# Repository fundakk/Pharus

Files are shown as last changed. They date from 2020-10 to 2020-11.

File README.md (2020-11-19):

# Pharus

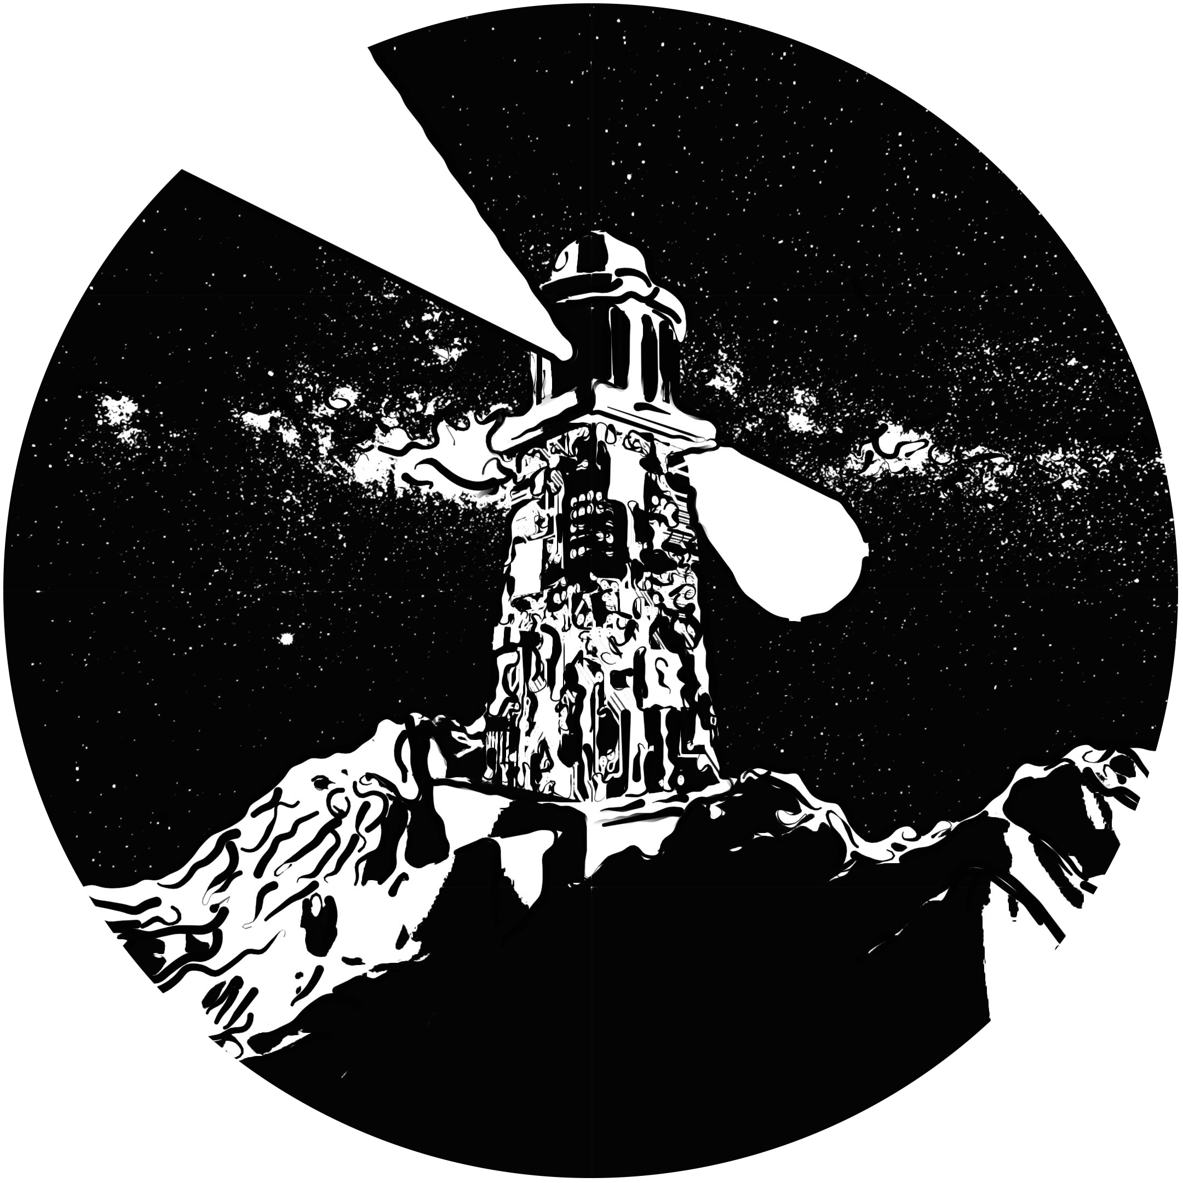
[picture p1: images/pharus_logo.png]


## Table of Content

- [1. Idea](#1-idea)
- [2. Hardware](#2-hardware)
  - [2.1 Basic assumptions](#21-basic-assumptions)
  - [2.2 Components](#22-components)
  - [2.3 Tools and machines](#23-tools-and-machines)
  - [2.4 Connection schematics](#24-connection-schematics)
- [3. Software](#3-software)
  - [3.1 Principle](#31-principle)
  - [3.2 Code](#32-code)
  - [3.3 SD card files structure](#33-sd-card-files-structure)
- [4. How to use](#4-how-to-use)
  - [4.1 Creator](#41-creator)
  - [4.2 Visitor](#42-visitor)
- [5. Scenarios](#5-scenarios)
  - [5.1 Basic Scenarios](#51-basic-scenarios)
  - [5.2 Gamification](#52-gamification)
  - [5.3 Event scenarios](#53-event-scenarios)
- [6. Weatherproof Case](#6-weatherproof-case)
  - [6.1 Parts](#61-parts)
  - [6.2 Printer setup](#62-printer-setup)
- [7. Step by step setup example](#7-step-by-step-setup-example)
  - [7.1 Connections](#71-connections)
  - [7.2 Arduino IDE, ESP and libraries](#72-arduino-ide-esp-and-libraries)
  - [7.3 Configuring Arduino IDE, compiling and uploading sketch](#73-configuring-arduino-ide-compiling-and-uploading-sketch)
  - [7.4 Using example files](#74-using-example-files)
  - [7.5 Testing](#75-testing)
  - [7.6 Assembling case](#76-assembling-case)
- [8. Notes](#8-Notes)

## 1. Idea

The project was implemented under the "Augmented Reality" program created by the Pilecki Institute. The basic idea of the project was to elevate perceiving art beyond the existing techniques - local exhibitions, talks, or lectures, where in times of social distancing, their organization was difficult and in some cases impossible.
The idea behind the project is the original description of Open Call:

“The sudden closure of museums, theaters, cinemas, the cancellation of concerts and meetings with authors posed many questions to the audience - participants and creators, managers, animators, researchers and educators about how to operate despite the imposed restrictions and forced them to seek new solutions. Restrictions affect not only the reception but also force the reorganization of the existing forms of activity. Ideas for a digital leap into the future are multiplying, lazily postponed for years. "

As part of this idea, the Pharus project was created. From Latin, it means "lantern" which directly refers to its function. It aimed to create a tool that would allow the transfer of information beyond the classic forms of communication, centralized around one space, but not directly using modern media such as the Internet / Facebook / Instagram, but using the technological achievements of modern times to the maximum.
The designed device, based on the ESP32 microcontroller, allows creating a local "beacon" that gives its own WiFi access point. Logging in from your phone to this network automatically (using the captive portal functionality) redirects the user to a website that contains content and functionalities stored only on the SD card connected to the device.

This solution is based on existing technologies, however, it stands out with a few details. The first thought is a QR code that redirects to specific websites. Unlike this technology, the project does not require any additional applications to read the code, redirects are automatic, without need for additional link clicks, and independent of Internet access. The second thought is a commercial beacon system, used, for example, in museums. The thing that distinguishes the project from such ready-made applications is that you can achieve goals without the use of external applications or expensive devices, significantly extending the range of usage for less commercial installations.

In terms of technology, the project is based on current IoT solutions. The project uses the Lolin32 lite prototype board, together with an external microSD card reader, to create a hotspot after connecting to which, a user is redirected to a website located on the card connected to the device. In addition, the project provides for 3 types of power supply - mains power (via 5V charger), battery power (using 18650 batteries, using a built-in battery charging system), and solar power (in the case of long-term use in spaces that do not have access to mains power). To extend possibilities of usage, the project involves the design of a 3D printed case, that can withstand rain and dust in outdoor scenarios.

The project is aimed at a very wide group of artists or organizations. It can be used by individual creators as well as smaller or larger festivals. The project can be implemented once (for a limited time) or it can be implemented as a permanent installation.

The project includes a couple of scenarios that have been divided into 3 layers - base scenarios, gamification scenarios, and event scenarios.

The first level represents the simplest way to use the device. It allows you to add a substantive comment in normally inaccessible places, to disperse the visiting by taking the content outside one space, or to divide the content and spread it over a specific expanse.

The second level introduces gamification scenarios. Based on the functionality of the base scenarios, it adds collecting, leveling, or city game elements to increase the attractiveness of the event.

The third level, based on gamification solutions, aimed mainly at festivals or organizations, is based on adding physical and digital rewards after achieving specific goals.

Of course, the listed scenarios are not final, the possibilities of use are unlimited and the listed scenarios are only examples of use.

## 2. Hardware

### 2.1 Basic assumptions

As a base idea of distributing project as CC-BY, that is available for as many people as possible, with different technical knowledge, it generates some assumptions that should be met for it to be useful.

#### 2.1.1 Ease of configuration and mounting

The first assumption is the ability to use and deploy devices with as many people and organizations as possible. Since many of these people would not have any technical background, this project aims to be as easy to deploy as possible, but without cutting usability.

This means, the device is constructed with modules, with as low amount of soldering possible, uses globally available components.

Programming should also be easy, step by step solution, wherein easiest scenarios will not require any programming knowledge.

#### 2.1.2 Price

The device is trying to keep its overall price as low as possible. For individual creators and smaller organizations cost of production of a single device at 100 euro might be too big or that sum of money could be used more wisely. The overall cost of a single device, in full setup, when bought on AliExpress will be at around 15 euro.

#### 2.1.3 Components availability

All components are globally available and can be replaced with alternatives.

#### 2.1.4 User friendly scenario

The idea of this solution is to make connections as easy as possible. That excludes any apps, complicated configuration, and connection. A user connects to a Wi-Fi access point (created by the microcontroller), opens the browser, and enters an address.

The best way would be to be redirected automatically to the desired local address (through captive portal) but it doesn't work with HTTPS.

#### 2.1.5 Universal installation

The project allows the installation of a device in many ways, indoor and outdoor. Energy can be provided with a power supply (standard cell phone charger), USB port in any device, batteries, and solar power.

### 2.2 Components

List of all components needed to assembly device, with extra information useful while ordering parts.

| Component | Description | Photo | USB Power Qty | Battery Power Qty | Solar Power Qty |
| --- | --- | --- | :---: | :---: | :---: |
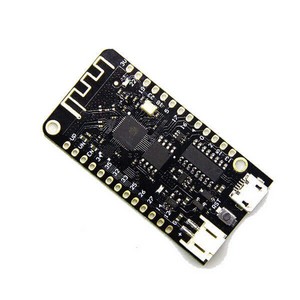
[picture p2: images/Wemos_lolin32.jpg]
Wemos
| Wemos Lolin32 lite | Main microcontroller. It's has been replaced with D32 or D32 Pro (which are slightly larger), but is still widely available |  | 1 | 1 | 1 |
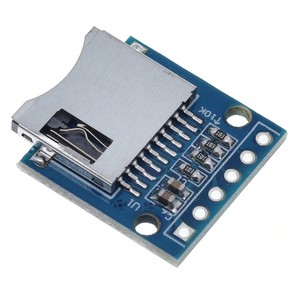
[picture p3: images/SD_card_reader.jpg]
Card_reader
| Card reader | Most basic card reader working on SPI. Be aware of power supply - some of them have built-in stabilizer 5V/3.3V and might work with microcontrollers without external 5V power supply. Card reader used in this project (and fitting into 3D printed enclosure is 18.5 mm width. Also, aim with one without pre-soldered connectors |  | 1 | 1 | 1 |
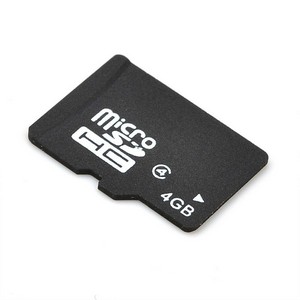
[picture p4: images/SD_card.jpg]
Card
| microSD card | Use any low storage (under 32 Gb) SDHC card. Speed is not important in this project. SD cards (such as 1 or 2Gb might, or might not work). |  | 1 | 1 | 1 |
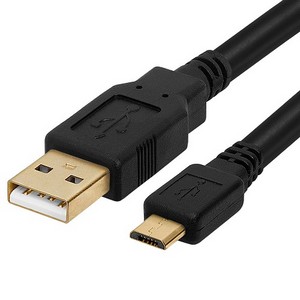
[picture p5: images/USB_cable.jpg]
USB Cable
| USB cable | Any micro USB type B cable, standard for most smartphones, preferred length of 1.5m |  | 1 | Only for upload | 1 |
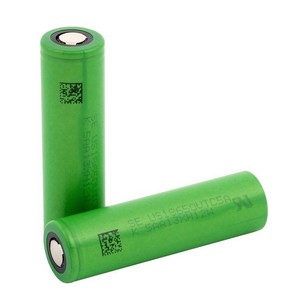
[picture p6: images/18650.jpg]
| Batteries | These are standard 18650 batteries widely used in many applications. Do not believe in ultra-high capacities. For the longest working time choose original batteries like sony with 2250 mAh. It's the best solution when batteries are the only power source so four of these can support power for over 100 hours. With solar power, you can settle with cheap ones (mine are 1800 mAh- tested) and cost 1/3 of the original price  |  | 0 | 4 | 2/4 |
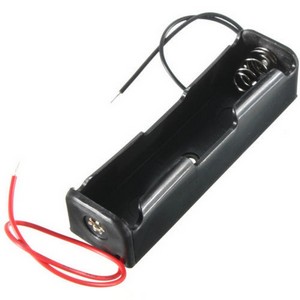
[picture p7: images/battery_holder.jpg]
Battery_holder
| Battery holders | Any most basic battery holders, smaller the better, just to allow an easy wire-to-wire connection. |  | 0 | 4 | 2/4 |
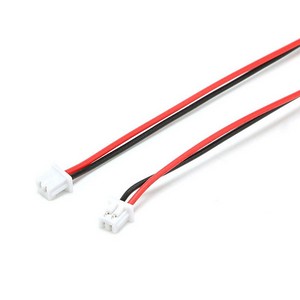
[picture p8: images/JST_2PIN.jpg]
Battery_connectors
| Battery connectors | JST PH2.0 2PIN. Be aware of colors and +/- on the Lolin board since they might not match with red and black colors on connectors (and reversing polarity will fry battery charging controller |  | 0 | 1 | 1 |
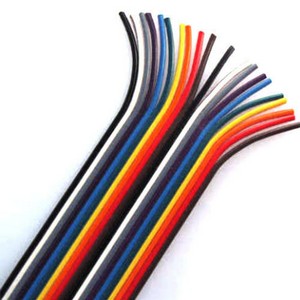
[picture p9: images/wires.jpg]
Wires
| Wires | I've been using 28AWG wires, but any would fit, smaller diameter is better for more flexibility |  | 0 | 1 | 1 |
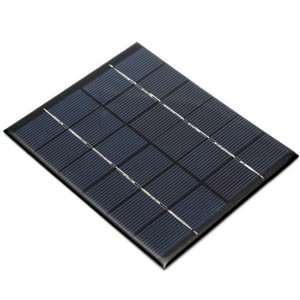
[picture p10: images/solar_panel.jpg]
Solar_Panel
| Solar power | Any solar panel 5-6V and between 2 to 3 W. Maximum charging current is 500 mA. Also, solar panels cannot be cheap - 2 euro solar panel won't be 2W. First of all check solar panel size - it should be at least 11x11 cm to provide enough power |  | 0 | 0 | 1 |
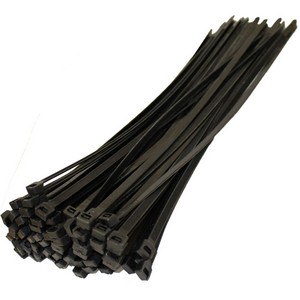
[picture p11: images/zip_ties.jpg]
Zip ties
| Zip ties | Zip ties for holding two pieces of a case together. You need a single 350x5mm zip tie or multiple shorter ones. |  | Only with case | Only with case | Only with case |
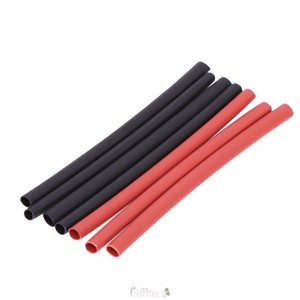
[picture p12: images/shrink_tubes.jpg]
Shrink tubes
| Heat shrink tubes | Or other insulation for soldered wires of batteries holders. For joining 4 wires you need 5/2.5mm and for 2 wires 4/2mm. |  | 0 |  4 cm |  4 cm |
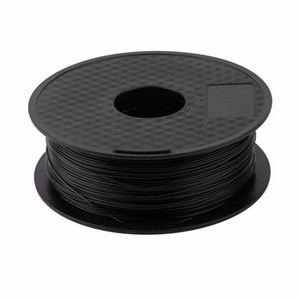
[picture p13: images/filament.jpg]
| Filament | Any filament that suits your preferred printing style |  | Only with case | Only with case | Only with case |

### 2.3 Tools and machines

List of tools required for this project.

| Tool | Description | Photo | Optional/Necessary |
| --- | --- | --- | --- |
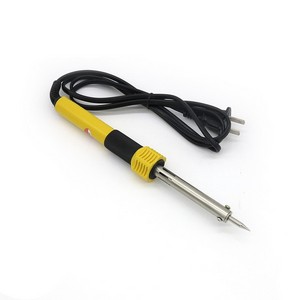
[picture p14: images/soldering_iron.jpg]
Soldering_iron
| Soldering iron | Any soldering iron, preferably with a small tip (for accuracy) |  | Necessary |
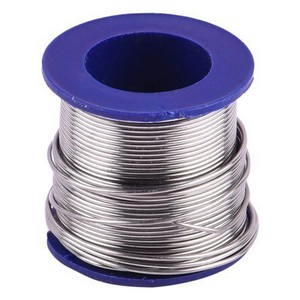
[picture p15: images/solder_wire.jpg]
Soldering_wire
| Solder Wire | Lead-free soldering iron |  | Necessary |
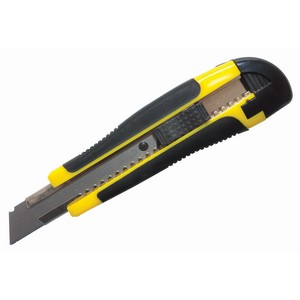
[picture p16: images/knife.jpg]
Knife
| Knife | Upholstery knife or any other for stripping wires. You can also use wire stripper but due to small diameters and a small amount of stripped wire it's easier to use a knife |  | Necessary |
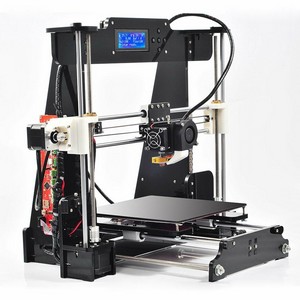
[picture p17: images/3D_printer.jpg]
3D printer
| Generic 3D printer | Used for printing weatherproof case |  | Optional |

### 2.4 Connection schematics

The device can be connected in 3 possible ways, that depend on a possible power source.

#### 2.4.1 Local power supply

In this case, no solar panels or batteries are needed.

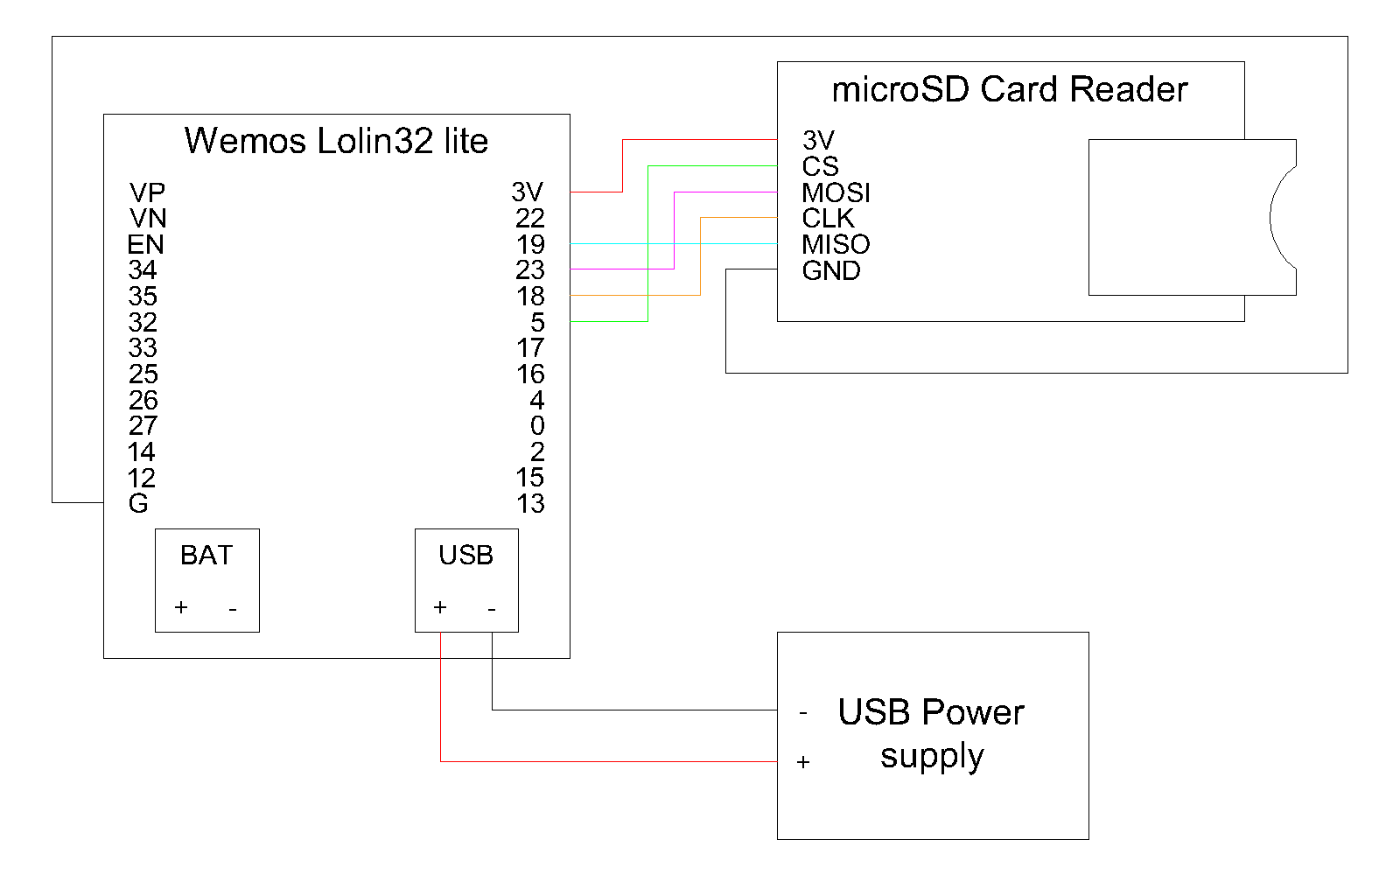
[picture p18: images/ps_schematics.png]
Schematics


#### 2.4.2 Batteries

To maintain 3 days operation it is recommended to attach at least 4 batteries.

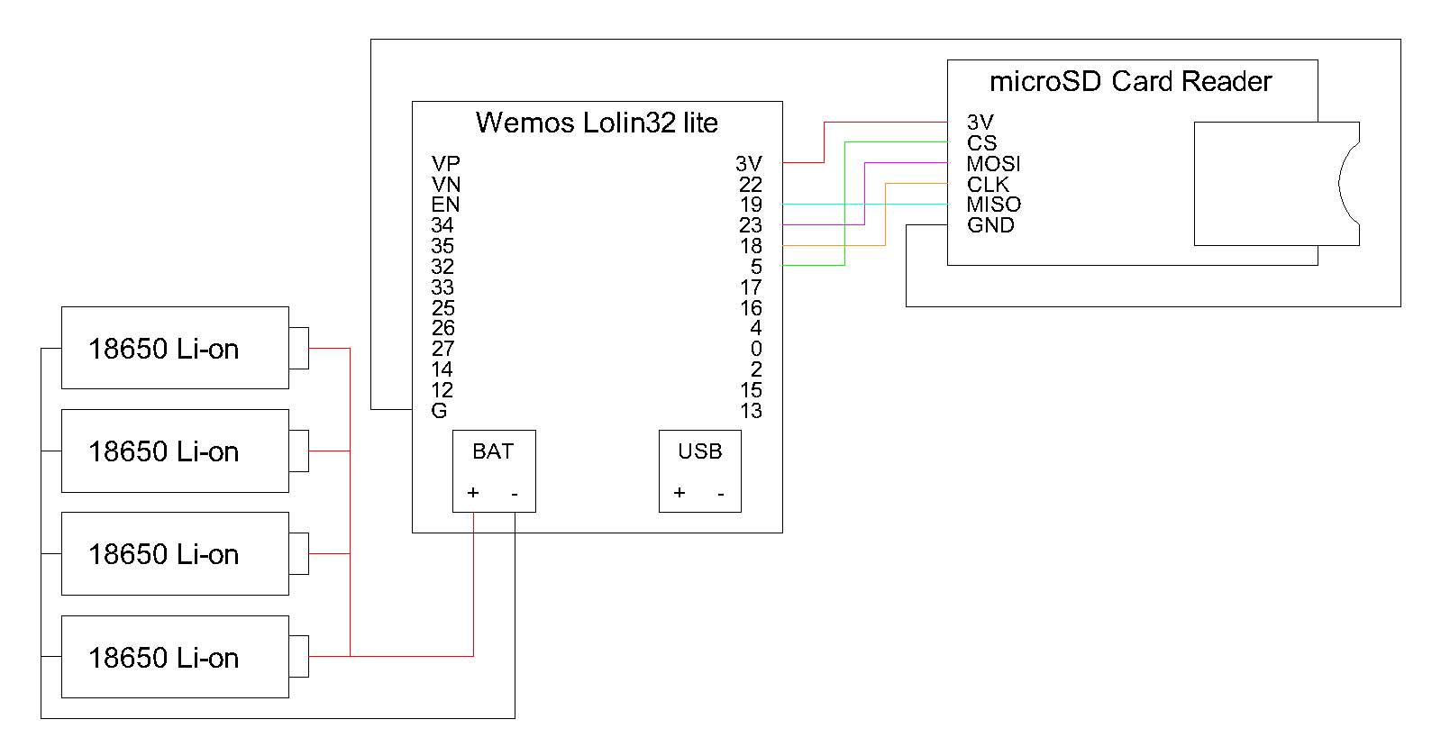
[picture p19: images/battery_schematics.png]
Schematics


#### 2.4.3 Solar panel

For a constant solar panel power supply, it is recommended to attach at least 2 batteries - this allows to last at least one day of bad weather.

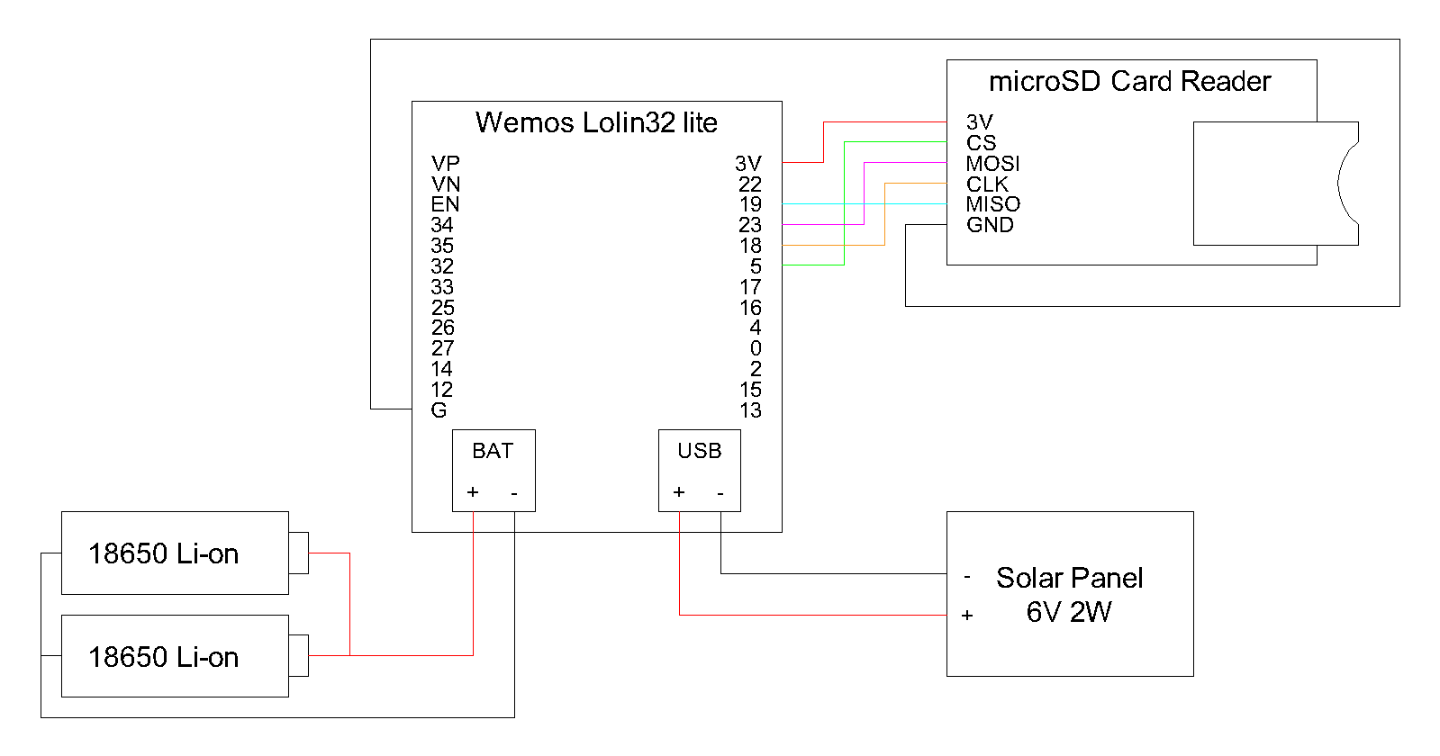
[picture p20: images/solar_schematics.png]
Schematics


## 3. Software

### 3.1 Principle

The main functionality of the software is to:
- create a WiFi access point
- create a DNS server
- create Asynchronous Web Server
- access files on a microSD card

This way user, after connecting to a WiFi network and opening the browser will be redirected to the local webserver. All files for this webserver are hosted on a microSD card.

### 3.2 Code

Include libraries

	#include <DNSServer.h>
	#include <WiFi.h>
	#include <AsyncTCP.h>
	#include "ESPAsyncWebServer.h"
	#include "SD.h"
	#include <Wire.h>
	
Here you can change SSID name:

	//CHANGE YOUR SSID NAME HERE
	const char* ssid = "PHARUS"
	
Declare DNS server and Web Server

	DNSServer dnsServer;
	AsyncWebServer server(80);

Declare new handler class

	class CaptiveRequestHandler : public AsyncWebHandler {
	  public:
	    CaptiveRequestHandler() {}
	    virtual ~CaptiveRequestHandler() {}

	    bool canHandle(AsyncWebServerRequest *request) {
	      //request->addInterestingHeader("CAPTIVE");
	      return true;
	    }

	    void handleRequest(AsyncWebServerRequest *request) {
	      Serial.println("Requested index.html");
	      request->send(SD, "/index.html", String(), false);
	    }
	};

This part is self-explanatory. It's starting serial communication, initializing SD card (and printing of what is on that card), and starting Wi-Fi Access Point and DNS server.

	void setup() {
	  Serial.begin(115200);

	  // initialize SD card
	  Serial.println("::::SD::::");
	  if (!SD.begin()) {
	    Serial.println("Card Mount Failed");
	    delay(3000);
	    Serial.println("Restarting");
	    ESP.restart();
	  } else {
	    Serial.println("Card Mounted");
	  }
	  uint8_t cardType = SD.cardType();
	  Serial.print("Card type: ");
	  Serial.println(cardType);

	  listDir(SD, "/", 2);
	  Serial.println("::::/SD::::");
	  Serial.println("");

	  WiFi.softAP(ssid);
	  dnsServer.start(53, "*", WiFi.softAPIP());
	  Serial.println(WiFi.softAPIP());

This is an important part. Client requesting empty will be given index.html file from SD card. For other files, requesting for example "/image.jpg" will load "image.jpg" from the SD card. Each server.on can be copied and modified to allow adding extra files that can be read from the SD card. In the end, we call a new handler that will load the main index.html file. All is finished by starting a web service.

	  server.on("/style.css", HTTP_GET, [](AsyncWebServerRequest * request) {
	    Serial.println("Requested style.css");
	    request->send(SD, "/style.css", "text/css");
	  });
	  server.on("/background.jpg", HTTP_GET, [](AsyncWebServerRequest * request) {
	    Serial.println("Requested background.jpg");
	    request->send(SD, "/background.jpg", "image/jpg");
	  });
	  server.on("/image1.jpg", HTTP_GET, [](AsyncWebServerRequest * request) {
	    Serial.println("Requested image1.jpg");
	    request->send(SD, "/image1.jpg", "image/jpg");
	  });
	  server.on("/image2.jpg", HTTP_GET, [](AsyncWebServerRequest * request) {
	    Serial.println("Requested image2.jpg");
	    request->send(SD, "/image2.jpg", "image/jpg");
	  });
	  server.on("/image3.jpg", HTTP_GET, [](AsyncWebServerRequest * request) {
	    Serial.println("Requested image3.jpg");
	    request->send(SD, "/image3.jpg", "image/jpg");
	  });
	  server.on("/image4.jpg", HTTP_GET, [](AsyncWebServerRequest * request) {
	    Serial.println("Requested image4.jpg");
	    request->send(SD, "/image4.jpg", "image/jpg");
	  });
	  server.on("/sound.mp3", HTTP_GET, [](AsyncWebServerRequest * request) {
	    Serial.println("Requested sound.mp3");
	    request->send(SD, "/sound.mp3", "sound/mp3");
	  });
	  server.on("/movie.mp4", HTTP_GET, [](AsyncWebServerRequest * request) {
	    Serial.println("Requested movie.mp4");
	    request->send(SD, "/movie.mp4", "movie/mp4");
	  });

	  server.addHandler(new CaptiveRequestHandler());

	  server.begin();
	}

Loop only checks for incoming requests to redirect them to the local address. It's not the best solution (but the only one available right now) - it does not redirect from HTTPS so it's not very useful with modern websites and browsers - but since it does nothing bad, and in some cases of HTTP addresses redirects to webserver - so this part is left to be.

	void loop() {
	  dnsServer.processNextRequest();
	}

	void listDir(fs::FS &fs, const char * dirname, uint8_t levels) {
	  Serial.printf("Listing directory: %s\n", dirname);

	  File root = fs.open(dirname);
	  if (!root) {
		Serial.println("Failed to open directory");
		return;
	  }
	  if (!root.isDirectory()) {
		Serial.println("Not a directory");
		return;
	  }

The last function lists all files on the SD card.

	  File file = root.openNextFile();
	  while (file) {
		if (file.isDirectory()) {
		  Serial.print("  DIR : ");
		  Serial.println(file.name());
		  if (levels) {
			listDir(fs, file.name(), levels - 1);
		  }
		} else {
		  Serial.print("  FILE: ");
		  Serial.print(file.name());
		  Serial.print("  SIZE: ");
		  Serial.println(file.size());
		}
		file = root.openNextFile();
	  }
	}

### 3.3 SD card files structure

All files must be placed directly on the SD card. They cannot be placed in any other folder and need to have specific names:

| File name | Description | Mandatory |
| --- | --- | --- |
| index.html | Main HTML file, webpage | Yes |
| style.css | CSS file with styles | No |
| background.jpg | Background image for better visual reception | No |
| image1.jpg | First of four available image files supported by ESP code | No |
| image2.jpg | Second of four available image files supported by ESP code | No |
| image3.jpg | Third of four available image files supported by ESP code | No |
| image4.jpg | Fourth of four available image files supported by ESP code | No |
| movie.mp4 | Movie file available to be included on webpage | No |
| sound.mp3 | Sound file available to be included on webpage | No |

Be aware, that image files must be saved as jpg, not jpeg.

There is no limit on the size of files, but be aware that this is not a high-speed connection. 100 Mb video file will load in a very long time, but will not play continuously, since transfer speed is to low. Stick with small files. After uploading files test with your phone if it works smoothly. If not, compress files.

## 4. How to use

This section will explain how to use this device - both from the creator (organizer) and visitor perspective.

### 4.1 Creator

1. Choose your scenario. Think about how you want to use, where, what content you want to deliver. You can use example scenarios or think of something new. Some ideas can be found in section 5. Scenarios.

2. After creating a scenario, choose the right hardware solution. Use the following diagram to determine what hardware to use in each location:

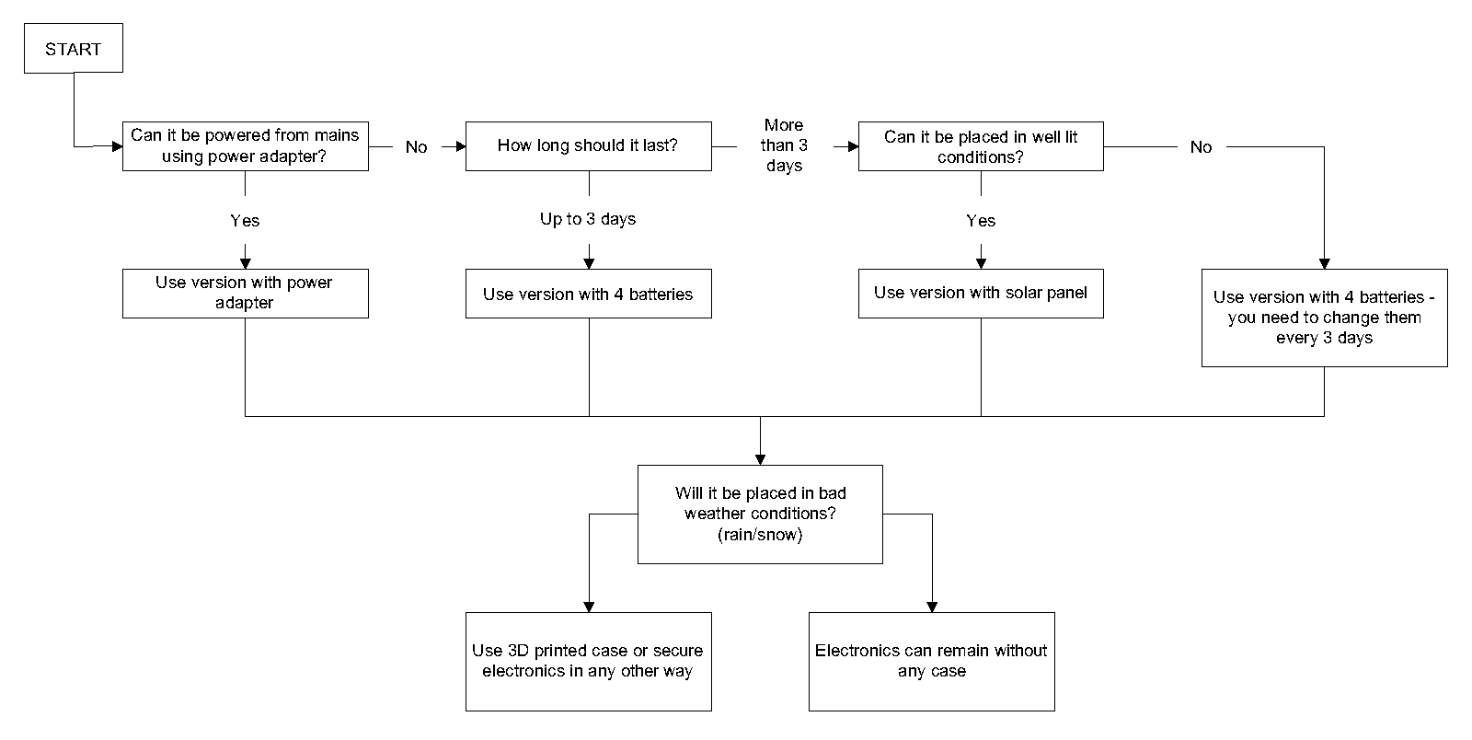
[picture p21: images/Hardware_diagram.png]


3. Gather all required media - images, movies, sounds, and texts. Prepare HTML files and media files according to examples, required formats, and data structure. Detailed information is in sections 3.3 SD card files structure and 7.4 Using example files

4. Assemble hardware (section 7.1 Connections), upload software (section 7.3 Configuring Arduino IDE, compiling and uploading sketch) and eventually print and assemble case (7.6 Assembling case).

5. When all devices are ready, place them at chosen locations.

6. Now you need to let your visitors know about it. It can be done in different ways, but the simplest way would be to use social media posts. You need to inform your guests about a few things:
  - that this solution is available and they can get extra content by using their phones
  - step by step solution (like the one below) how to exactly connect
  - locations of devices - you can just post address, pin on online maps, or you can add geocaching solutions by posting geographical coordinates, or even a picture of a certain place in the city. You can also start a city game scenario by showing the location of the first device and putting the rest of the locations on subsequent devices.

### 4.2 Visitor

1. After arriving in the location indicated by the organizer, bring up available WiFi networks.

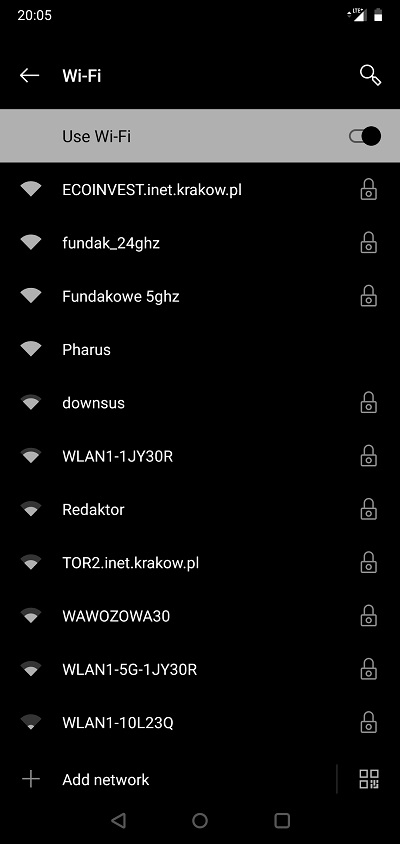
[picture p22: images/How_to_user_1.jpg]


2. Connect to WiFi with name described in the event

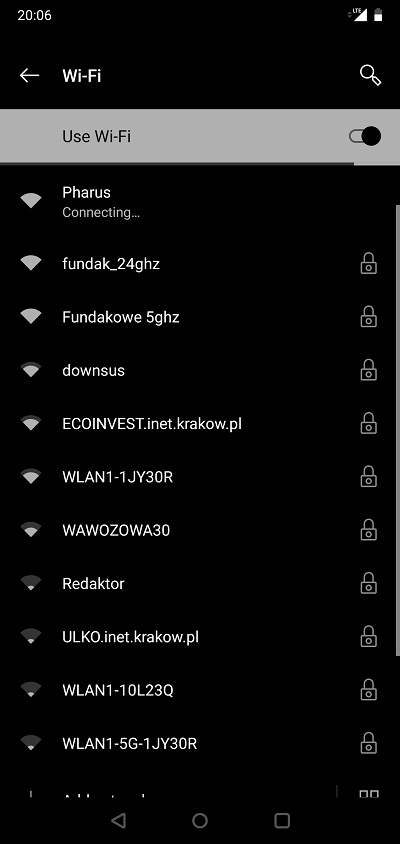
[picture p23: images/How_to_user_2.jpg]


3. You should see a popup that will say "Sign in to a WiFi network" or similar, based on your smartphone

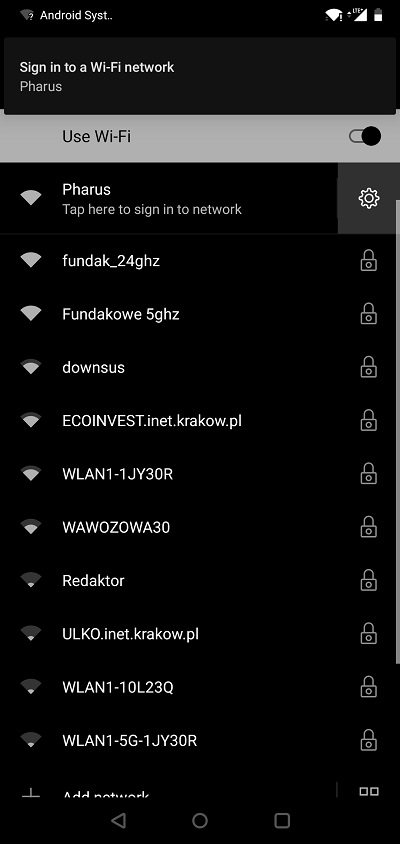
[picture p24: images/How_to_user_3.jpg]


4. Click on popup or network name again to be redirected to a local website with the desired content.

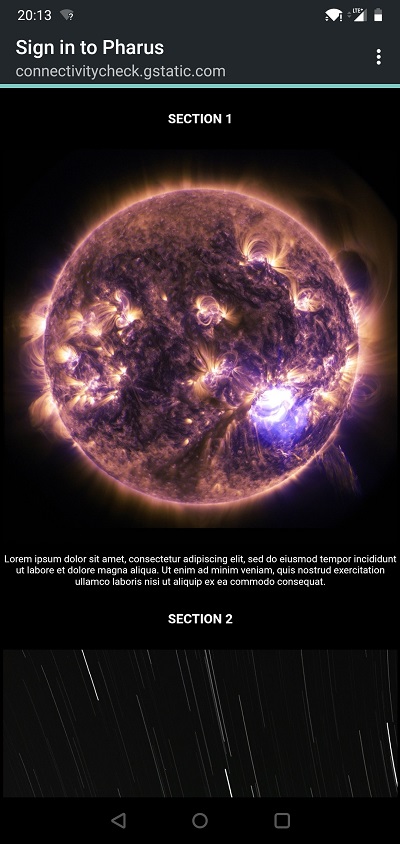
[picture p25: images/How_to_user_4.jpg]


5. In rare cases that captive portal is not compatible with your smartphone, bring up a web browser and enter 192.168.4.1

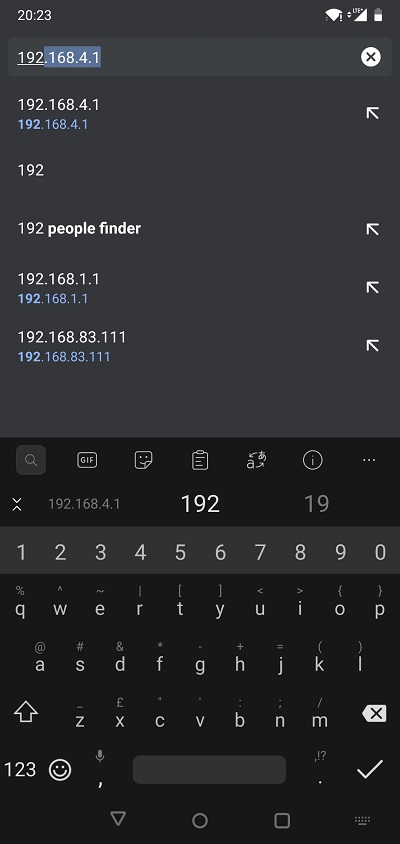
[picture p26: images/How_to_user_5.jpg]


## 5. Scenarios

This project involves three levels of usage scenarios. Each level is more complex and has its designated use.

1. The First level are basic scenarios - these are the most common and simplest form us using a device. Generally, they are used to deliver extra content without squeezing visitors within a single room. Most basic forms include delivering single or multiple photos, text, video, or audio, but they are not limited to it.
2. Second level are gamification scenarios - their purpose is to increase the engagement of users. They require more advanced technical solutions, but with the right scenarios and ideas can greatly increase the involvement of visitors, leave them with a better experience, and supply organizers with extra tools.
3. Third level are event solutions - these are mostly festival/organization scenarios that are based around increasing involvement using gamification and external motivation with real-world awards.

### 5.1 Basic Scenarios

Basic scenarios are the first step in delivering content to the recipient. They represent the simplest and most standard applications of the device.

Three sub scenarios can be included in its usage:

#### 5.1.1 Substantive comment

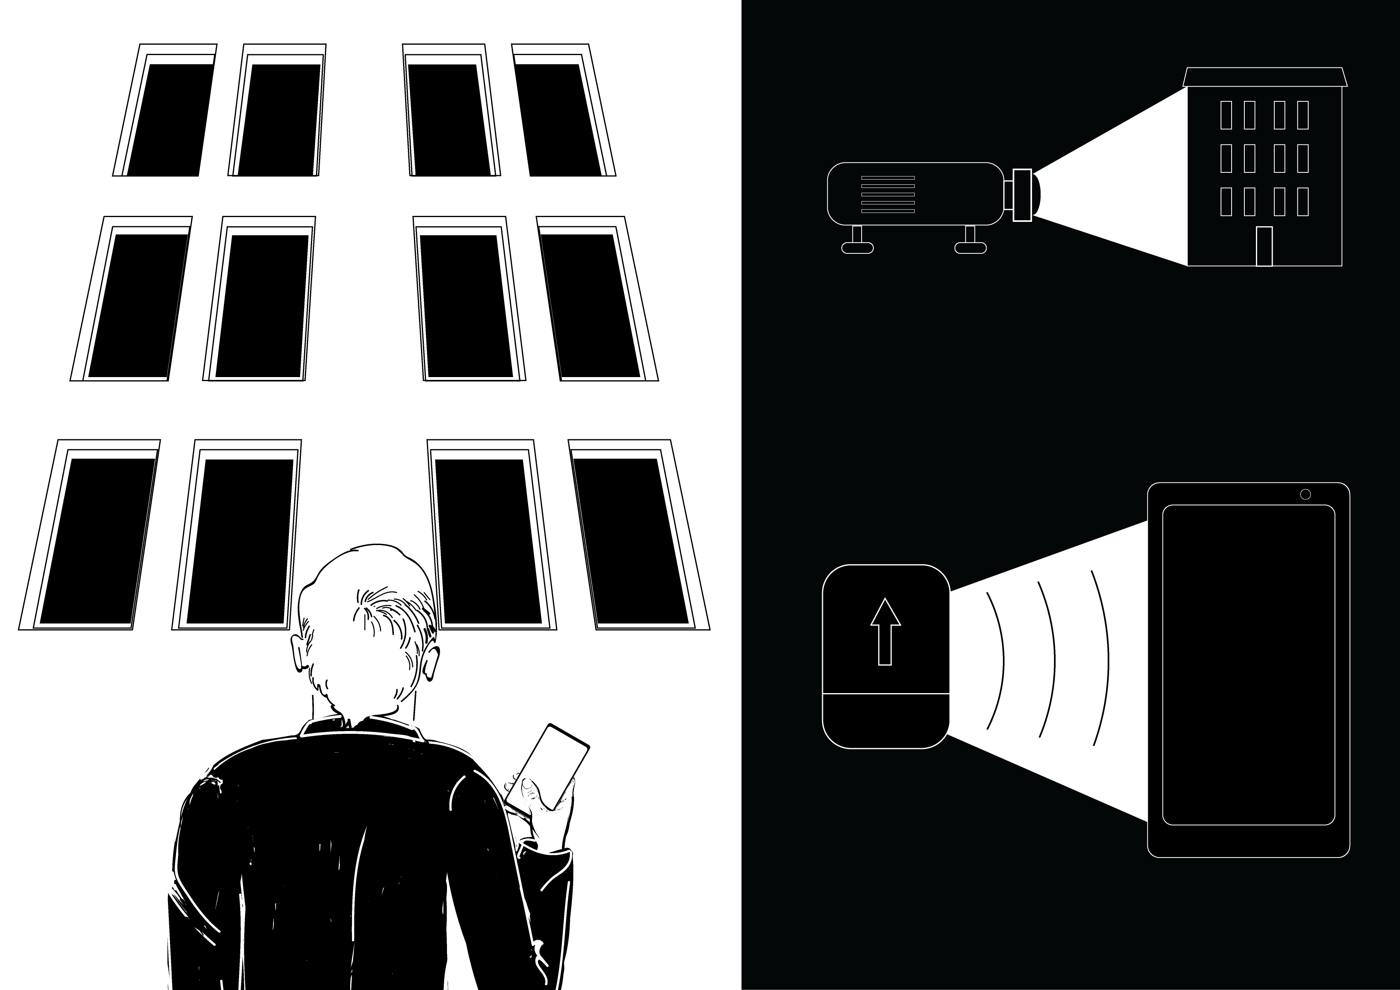
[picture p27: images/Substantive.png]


This scenario allows adding extended explanation, comment, history fact, author biography to a presented art piece when no other forms are available. It would apply mostly to historical points, big scale installations, urban art, murals, or mappings, where scale or location do not allow to add a printed description, or it would be easily missed.

Examples of use:

- big scale mural, placed in an urban environment, have no way of including information about the artist and/or comment about the painting itself. Even if there is a possible way to place it, with such a scale it will be missed by visitors, which will take some space between the facade and viewing area. Connecting to a device will allow them to get this extra information on their phones.
- placing informational boards on historical buildings or monuments might not be possible. The device placed in its close perimeter will allow sharing facts, photos, or other extra information about its origin, or important people who lived there.
- large scale installation or video mapping during the festival will be hard to comment on, or at least present the author, because any informational slate will be lost in its scale. Using the device will allow delivering all information that could be shared, like artist bio, commentary, photos or movies of construction, etc.

#### 5.1.2 Scattered content

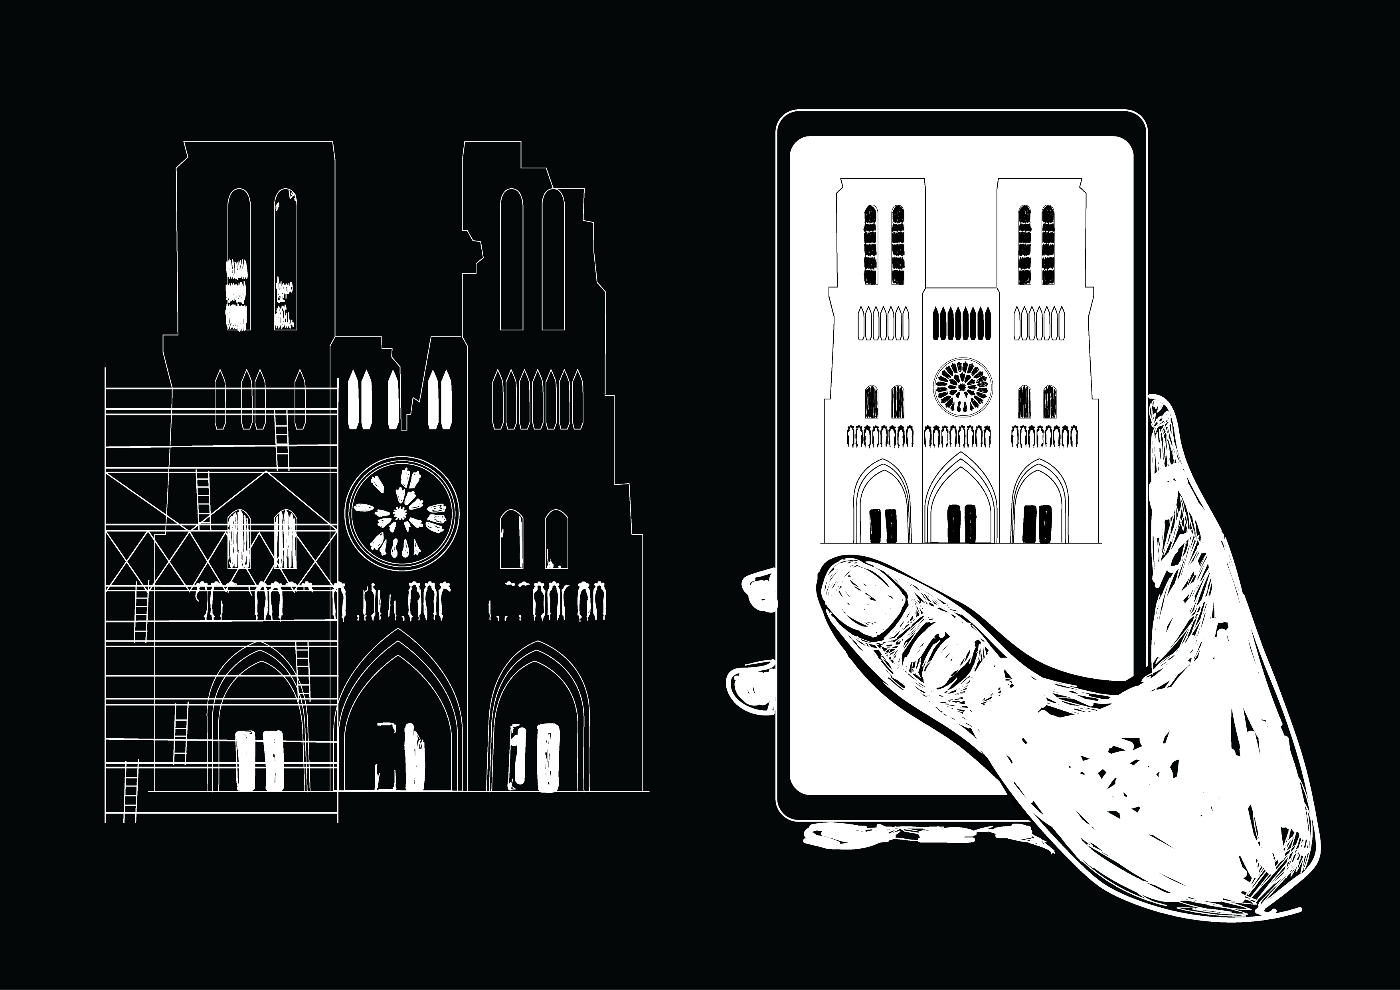
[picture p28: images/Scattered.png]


Scattering content allows taking art outside of the exhibition area. Multiple devices located in different places (within the city, country, or even globally), allows to scatter visitors and apply more social distancing in terms of art delivery. Each device will deliver single artwork in digital form. Scattering also allows moving some forms of art to places with more ambience.

Example of use:

- painter or graphic that creates landscape or urban architectural drawings/paintings can deliver his artworks exactly in places where they were created.
- sound artist or musician can move his creations to places with a better atmosphere or vibe, that can improve reception.
- any artist can place devices in public spaces or bars, as a form of expression or self-promotion.

#### 5.1.3 Extended content

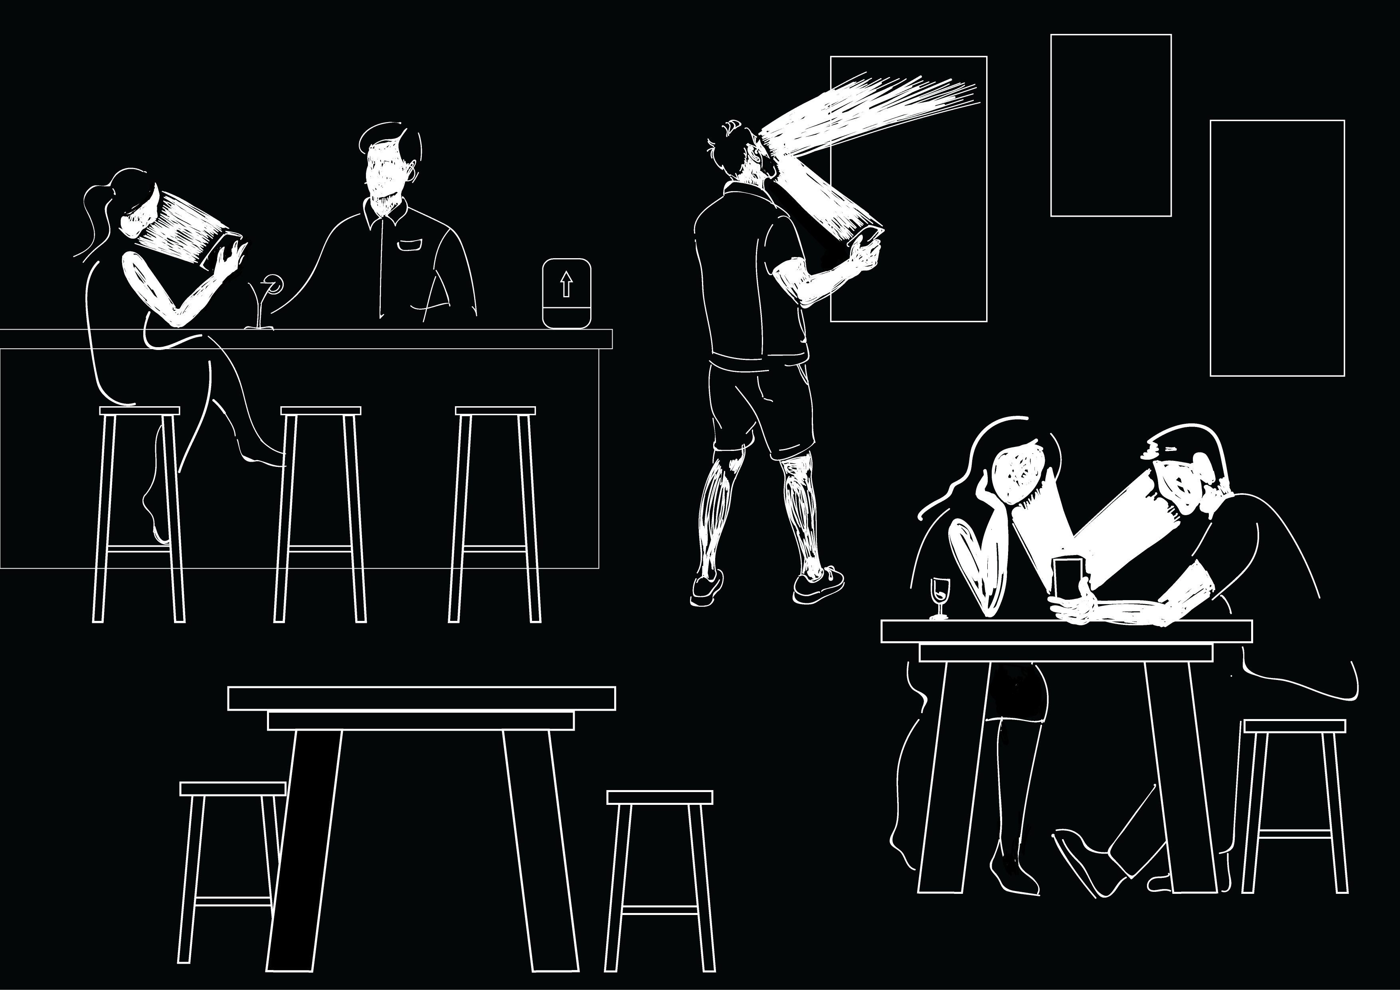
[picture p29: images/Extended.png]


Extended content is similar to a substantive comment, but instead of delivering comments or other text, it will deliver other art in digital form. It would fit in galleries, or at art exhibitions, where limited space (or budget) does not allow to put extra artworks.

Example of use:

- gallery with limited space can only display a few paintings out of series. The device can be used to present other paintings in digital form.
- emerging artist, instead of only his illustrations would like to show also his digital movies. Setting up for example 4 TV or projectors require equipment that he has no access to, and is above his budget in case of renting or buying. Setting up devices allows him to present his other work budget-wise way.
- musician or artist can set the device in a local restaurant/bar/pub where he hanged a poster about his event and add extra involvement and deliver more information.

### 5.2 Gamification

Gamification scenarios are the next level of device use. Based on basic scenarios they are used to liven up the experience of visiting galleries/festivals. They are an intermediate element between classical marketing and non-commercial promotion. They allow to extend events in time and increase visitor engagement, which has an application both to individual artists planning to set up bigger exhibitions, and festivals trying to increase their guests' activity.

Even due highly recommended, basic scenarios do not require any other external elements. Gamification scenarios must include at least social media posts to guide the guest to the required spaces.

Gamification is the usage of game elements or game creation techniques, in areas not connected to gaming. Its goal is to increase activity, motivate, stimulate learning, and problem-solving. By using internal and external motivation, it puts users into intense interaction with the event.

Including gamification in process of exhibitions allows to:
- extend the time of exhibition/festival,
- adds extra engagement,
- provides additional tools for the social media team,
- increase activity in less frequented parts of the festival.

Possible scenarios are unlimited and many game mechanics can be transferred, for example:
- collecting elements
- ratings
- goals
- increasing experience/levels
- badges
- solving riddles
- storytelling

Since there is a lot of possible applications, only a few will be shown with an example.

#### 5.2.1 Collecting

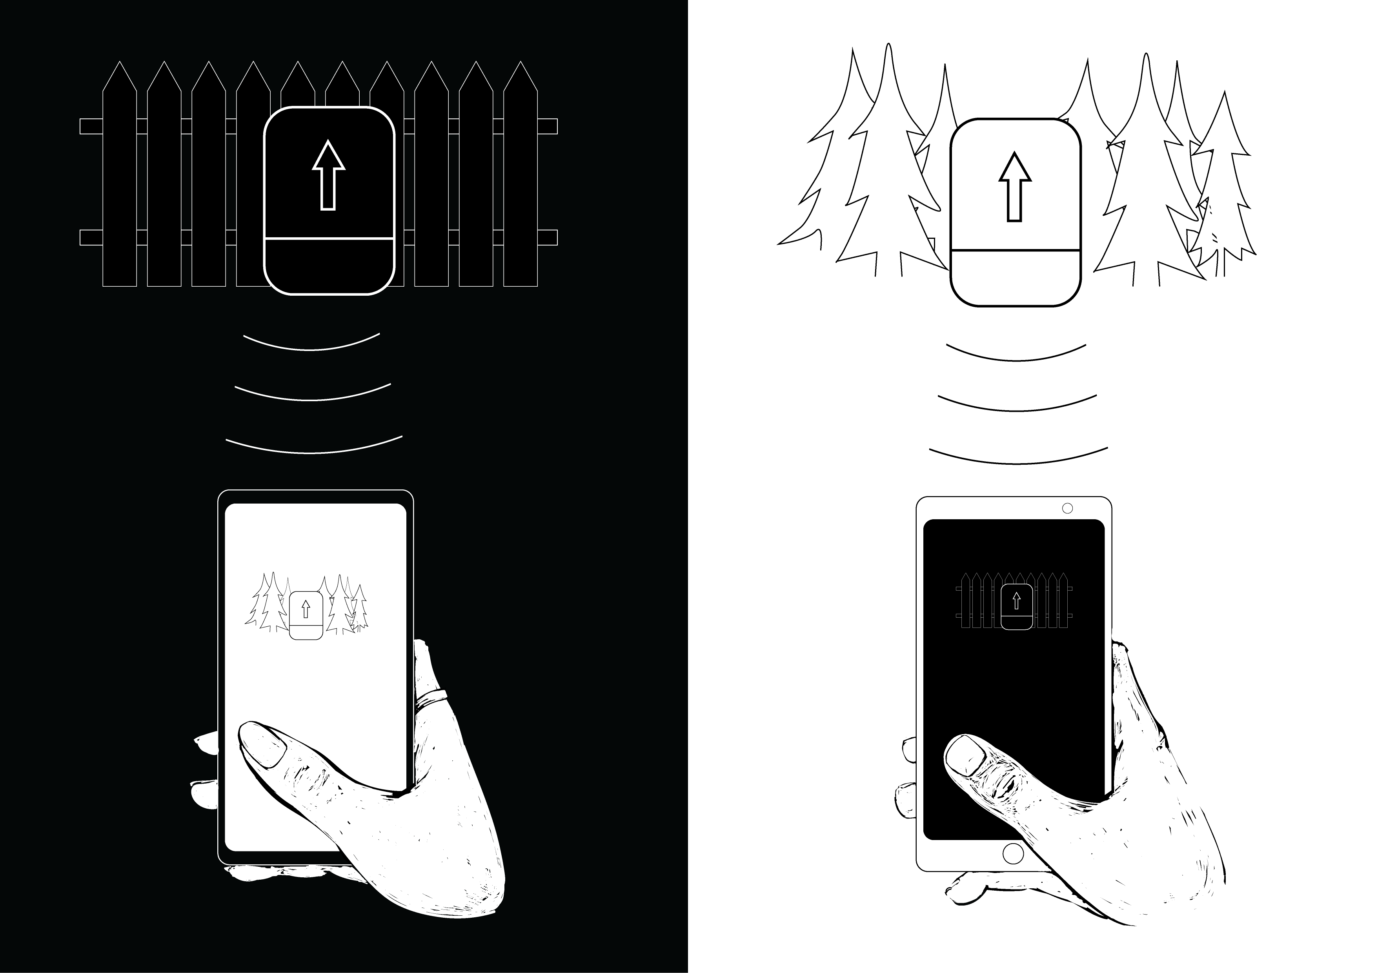
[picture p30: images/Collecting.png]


Collecting elements increase the user's activity, because each element of the collection have a bigger value than a single one. People are naturally conditioned to fill holes and complete patterns, so that’s why a person that has not visited all sites at the festival, will go to the last one, just to complete the collection.

This scenario allows users to visit multiple destinations, log into each one of them, and because of logging in, collect part of the reward. This could be:
- wallpaper
- badge (all collection of badges)
- experience points
- artwork
- story

The main idea of it is to cut one single element into multiple parts, so the user can experience filling each part as an accomplishment.

Example of use:

- festival is spread into six locations - each holding its own exhibition or event. Setting devices in each one of these places and connecting to them will gradually reveal wallpaper to be download. This could convince some users to visit a remote location that otherwise would be omitted.
- individual artist can set up devices in multiple places, and by posting information about their locations on social media (for example one every 3 days), increase visitor's activity, keep the event alive for a longer time and finally reward the active visitors with a digital piece of art.
- organization or artist could spread devices around the city, and implementing a geocaching mechanism (by posting geographical coordinates or even photos of these places) could activate visitors to participate more intensely in the event.

#### 5.2.2 Levelling

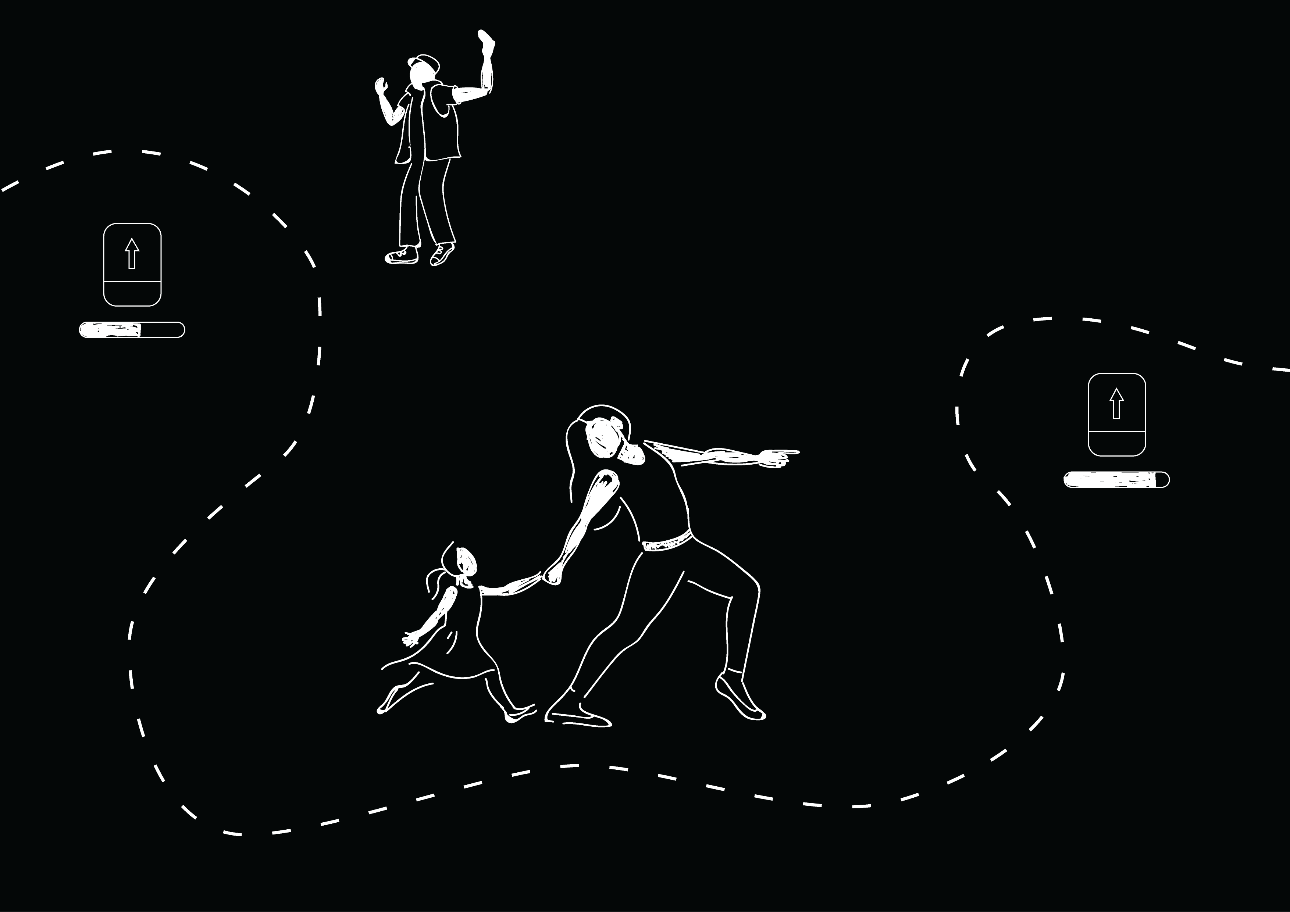
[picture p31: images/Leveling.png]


Designed to rather lightweight events, this scenario is based on collecting experience points instead of parts of the collection. It can provide deeper involvement - except for collecting elements, it includes a psychological element of progress and achievements. But due to the fact that it is clearly a gaming solution, it might not be interesting to some groups of visitors and even lower the rank of event, so it should be used carefully, and it fits more into "fun" festivals or activates designed for a younger audience.

Example of use:

- summer festival could set the device at each music stage, and change it for every artist allowing to collect as much event from the festival as possible, and award points (which will fill the progress bar to the next level). It would allow a user to brag around social media and increase the number of tagged posts.
- medieval festival could use multiple devices and by letting kids connect and gather experience points, will award them with the more powerful avatar, from example starting with standard infantry to a knight in shining armour. Each level would consist of a new illustration and historical information.

#### 5.2.3 Riddles solving

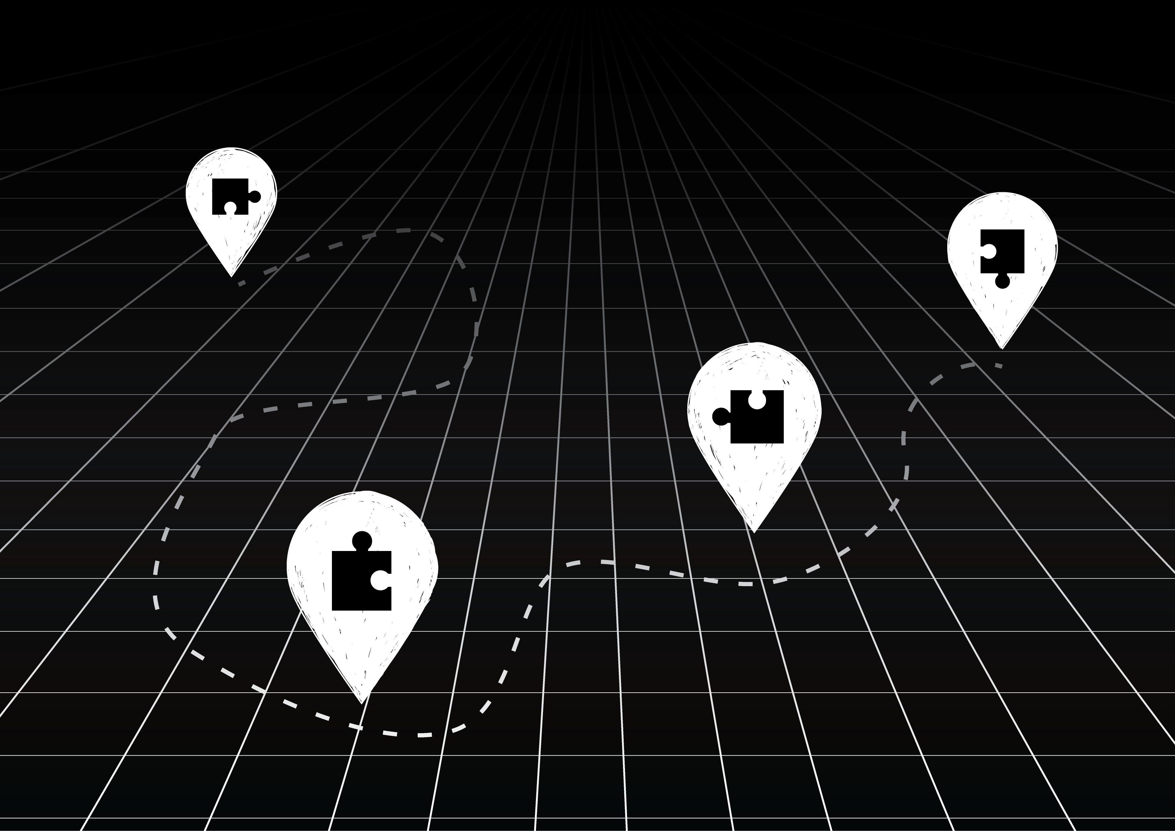
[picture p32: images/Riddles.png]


It can improve both leveling and collecting by adding a more advanced element of solving any kind of riddles. This could greatly benefit storytelling scenarios.

Examples of use:
- after logging in, the user is given part of the story. He has also a window to enter a reply to a question, concerning the surrounding location. After a proper answer, he will be revealed with another part. All devices around the city are part of one story.
- kids at the museum, after logging into the network, and before being able to level up, are required to answer a question with a piece of knowledge that can be found around the perimeter, which will stimulate learning.

### 5.3 Event scenarios

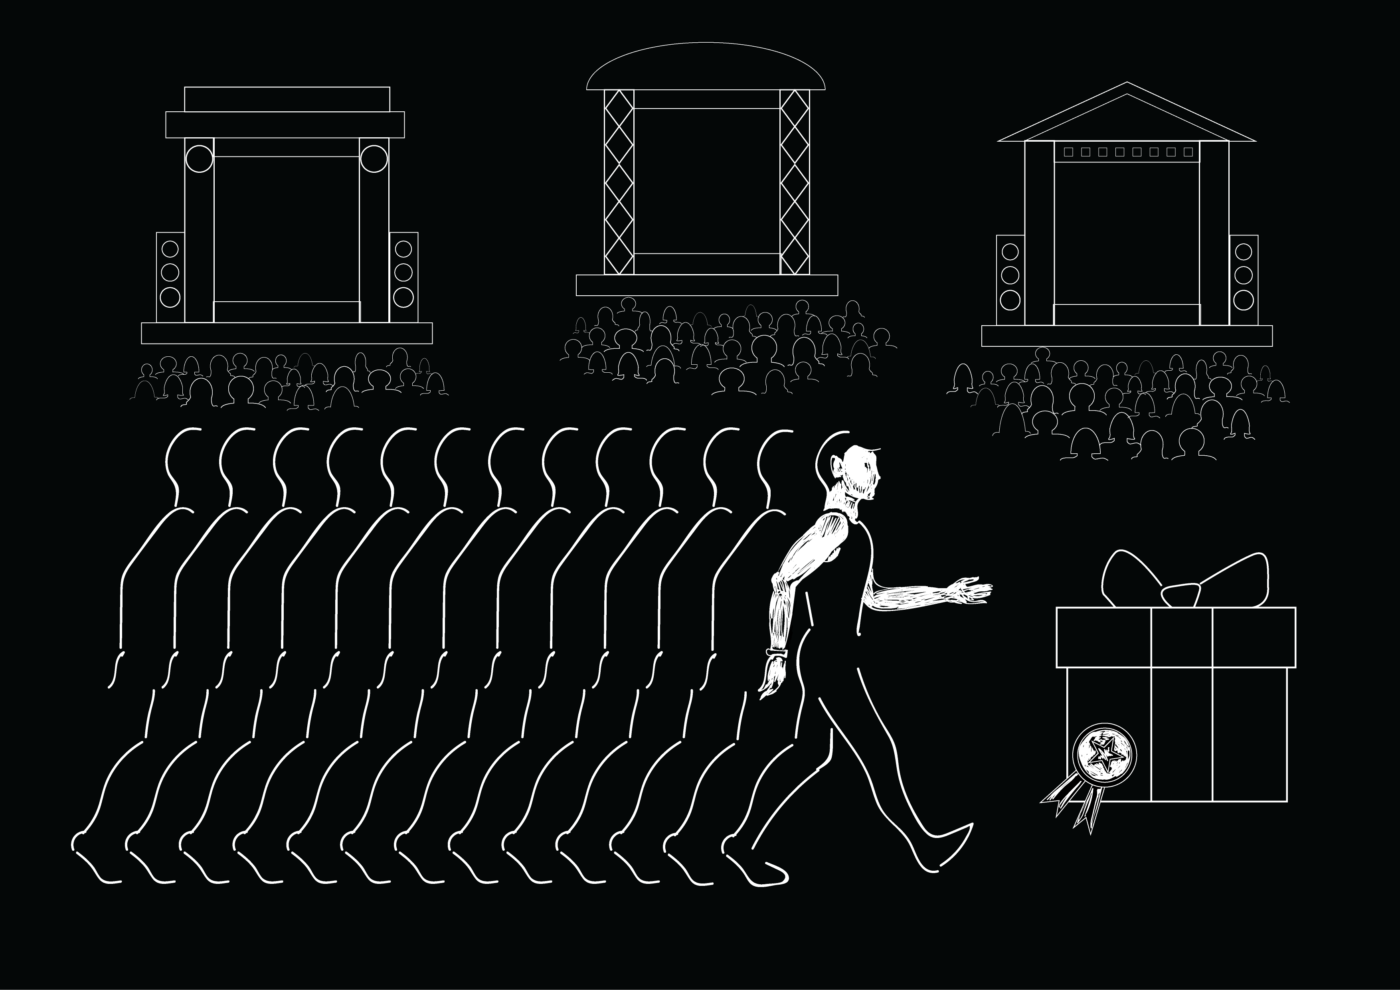
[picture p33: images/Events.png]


Event scenarios are the last level of engagement for visitors and are plainly a commercial form of rewarding activity. They are purely based on gamification scenarios that add extra, real world prizes. They should be thoroughly considered since making them too easy (or easy to cheat) with too big of a reward could have a disastrous impact on the event budget or at least public relations.

Since basically all gamification solutions could be applied, there are no sub-scenarios.

Some examples of how to include real-world prizes include:
- setting up hard storytelling/riddle city hunting, and collecting whole story (along with control codes) could be awarded a personal meeting with the main artist during the festival,
- festival lasts for a week. During that week there are several events, that guests can participate in. Going to every event and logging in, will generate a discount code for the last main event. Or allow for one free drink.
- just arriving at the music festival and logging in will result in participating in a draw for some merch.

## 6. Weatherproof Case

This project also includes a 3D printable case for components and batteries. Two versions are available - housing 2 and 4 batteries. The up arrow on the upper part shows the direction in which case should be mounted to maintain assumed IP33 weather resistance. The case also has compartments for holding spare SD cards - depending on a version from one to three extra cards.

Base ideas:
- weather resistance as IP33 - when mounted upright, electronics will be protected against rain and dust. The weak point is cable passthrough. It is left big to pull the micro USB connector without the need to cut the wire. It can be upgraded to IP68 by using silicone or glue.
- hard case - all walls are thick so it will protect electronics from physical damage
- steady mounting - batteries and ESP will have minimal movement to minimalize disconnections and shortcuts.
- closing should be as simple as possible - no screws or mechanisms - joining part would be accomplished by zip ties.
- low aesthetics - the case is not supposed to be pretty - it's always hidden and does not require to look good. It should be functional.
- 3D printable - can be printed without advanced slicing - no supports, overhangs and so.

### 6.1 Parts

| Part name | Description | Photo | Print Qty |
| --- | --- | --- | --- |
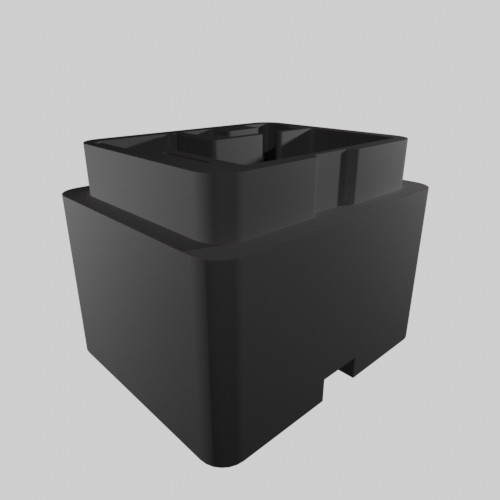
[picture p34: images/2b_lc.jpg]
| 2_batteries_lower_case | Bottom compartment part for 2 batteries setup |  | 1 |
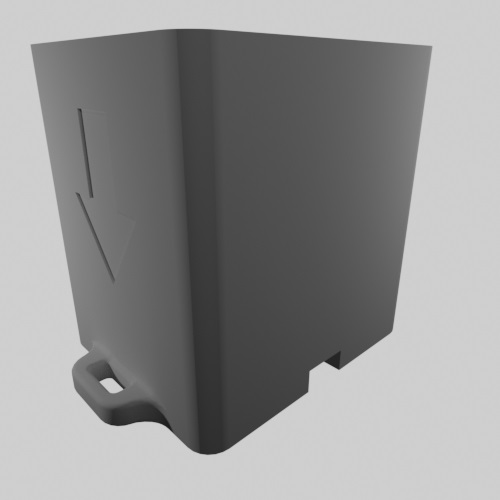
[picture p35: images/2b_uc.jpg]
| 2_batteries_upper_case | Top compartment part for 2 batteries setup |  | 1 |
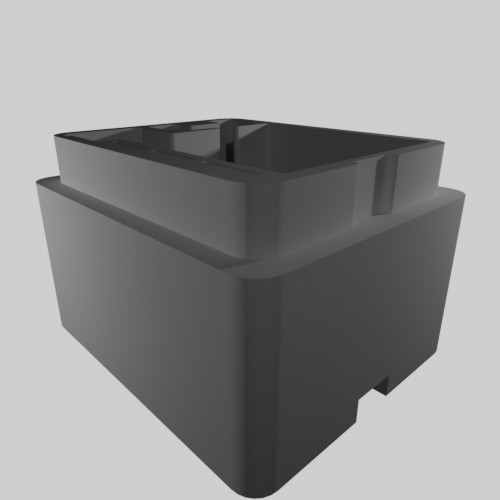
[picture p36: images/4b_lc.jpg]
| 4_batteries_lower_case | Bottom compartment part for 4 batteries setup |  | 1 |
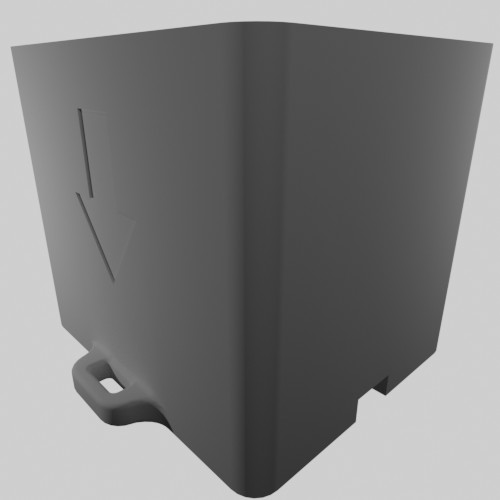
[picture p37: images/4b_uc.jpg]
| 4_batteries_upper_case | Top compartment part for 4 batteries setup |  | 1 |
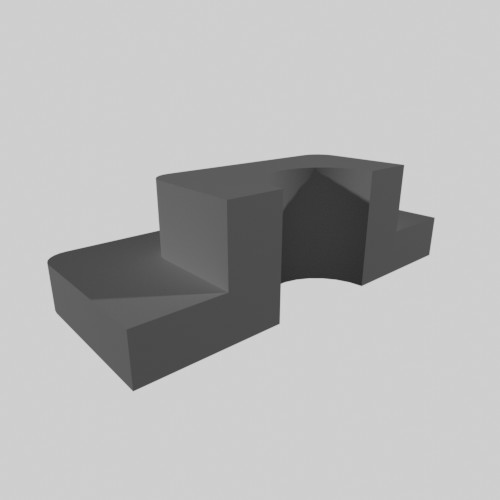
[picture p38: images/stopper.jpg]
stopper
| stopper | Blocking part fitted in lower part to block and tighten USB cable passthrough |  | 2 |

### 6.2 Printer setup

Basically, any settings and materials will be good for printing, so choose one best fitting your printer. Some suggested setting:
- 0.4mm nozzle
- 0.2 layer height
- 3 wall line count
- 4 bottom layers
- 3 top layers
- no support
- grid pattern infill with at least 20% density
- concentric top/bottom pattern
- any material, suggested PLA or ABS

## 7. Step by step setup example

### 7.1 Connections

These instructions show step by step connection when using a 3D printed case. If you are not planning to use a 3D printed case, you can connect the device with another length of cables, or even using headers and jumper cables.

1. Cut 6 pieces of wires each 10 cm. Strip about 2mm from both ends.

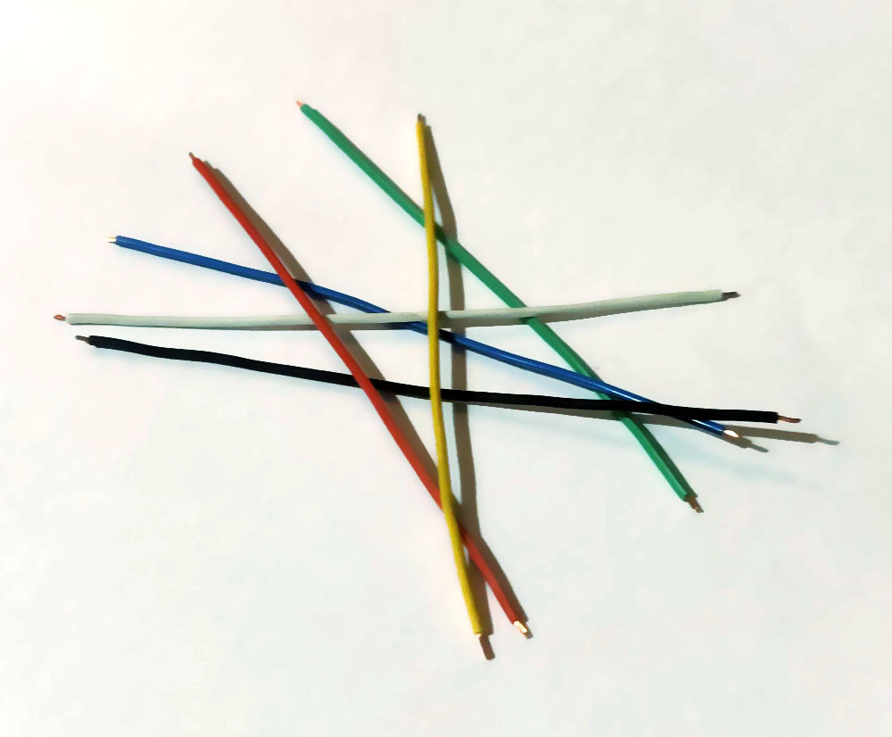
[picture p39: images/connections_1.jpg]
Connections


2. Solder wires to lolin32 from the bottom side of the board. Solder them to pins GND, 3.3V, 19, 20 23, 18, 5.

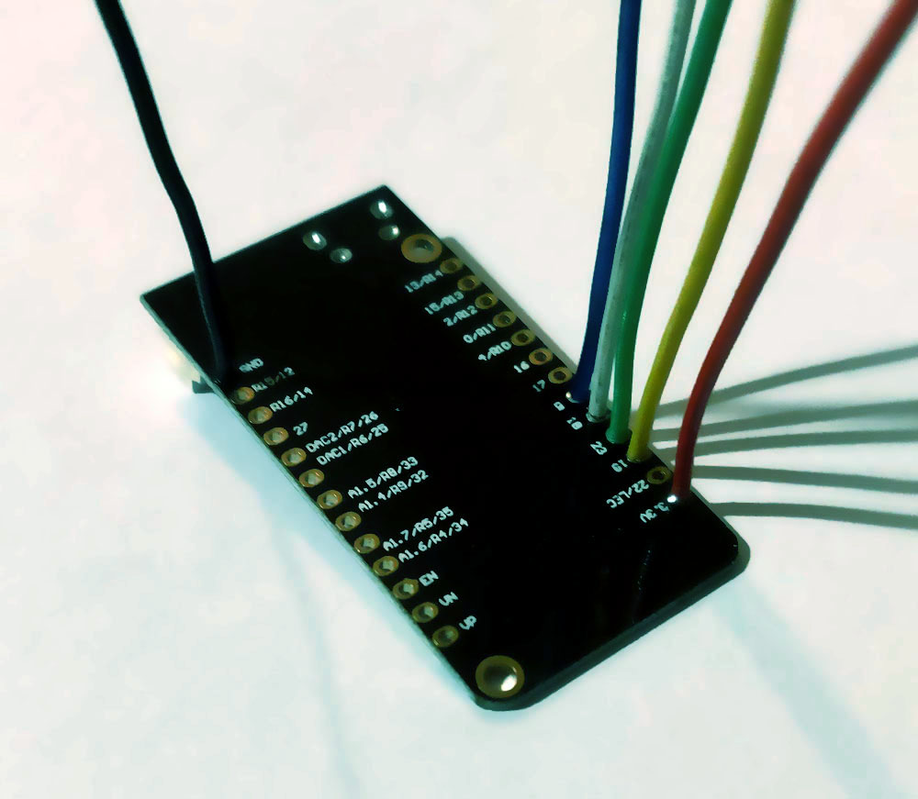
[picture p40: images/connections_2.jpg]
Connections


3. Solder another end of the wires to microSD card module, according to schematics.

Connections

4. Guide battery holder wires from bottom to right corner of batteries holder and then to the top. Guide top wires through the middle of the batteries pack and cut them just at the edge of batteries cases. Strip about 5mm from the end. If you are having problems with keeping cases together you can place batteries in and squeeze them with zip ties. Be extra careful for black and red wires not to touch each other.

Connections

Connections

5. Cut about 3 cm from JST connectors, strip them for about 5mm. Solder all battery and JST wires together. Do not forget to put on heat shrinking tubes and shrink them on soldered connections to insulate them. Check wires polarity with microcontroller board - if red wires are not connecting to **+** on the Lolin board, then switch wires in connectors.

Connections

6. Cut USB connector from a USB cable. Strip about 3 cm of main insulation, then cut out all extra wires except black and red. Stip the end of these wires for about 3mm.

Connections

7. Solder USB cable to the back of the solar panel. Red cable goes to **+**, black to **-**.

Connections

8. Secure wires with power tape.

Connections

9. Connect batteries to batteries JST socket, and plug USB connector to a USB socket on the Lolin board.

Connections

### 7.2 Arduino IDE, ESP, and libraries

This project will require to use of Arduino IDE to compile and upload code, with ESP32 boards and external libraries

#### 7.2.1 Installing Arduino IDE

Follow instructions on the official Arduino guide:

https://www.arduino.cc/en/guide/windows

#### 7.2.2 Installing ESP32 boards

This is an easy step by step solution on how to install ESP32 boards in Arduino IDE.

1) Open Arduino IDE
2) Click on **File** > **Preferences**
3) Under **Additional Boards Manager URLs** paste a link to Espressif boards manager *https://dl.espressif.com/dl/package_esp32_index.json*
4) Click **OK**
5) Go to **Tools** > **Board** > **Boards Manager**
6) Search for *ESP32*
7) Press the install button for the *ESP32 by Espressif Systems*
8) After few seconds it should be installed, after this click **Close**

#### 7.2.3 Installing required libraries

This project requires Asynchronous Web Server libraries. It consists of two packages:

- [ESPAsyncWebServer!](https://github.com/me-no-dev/ESPAsyncWebServer/archive/master.zip)
- [AsyncTCP!](https://github.com/me-no-dev/AsyncTCP/archive/master.zip)

Download both .zip packages and change their names by removing *-master* from the end of the filename.

Next:
1. Open Arduino IDE
2. Go to **Sketch** > **Include Library** > **Add .ZIP Library...**
3. Choose one of the downloaded libraries and click open
4. Repeat for the second library

### 7.3 Configuring Arduino IDE, compiling and uploading a sketch

After this, you are ready to upload software to the microcontroller. First, you need to setup Arduino IDE for proper settings.
1. Connect your Lolin32 board to the computer using a USB cable.
2. Open Arduino IDE
3. Go to **Tools** > **Boards:"XXXXXX"** > **ESP32 Arduino**  and choose *WEMOS LOLIN32*
4. Go to **Tools** > **Upload speed: "XXXXXX"** and choose *921600* or if it's not working try *115200*
5. Go to **Tools** > **CPU Frequency: "XXXXXX"** and choose *240 Mhz (WiFi/BT)*
6. Go to **Tools** > **Flash Frequency: "XXXXXX"** and choose *80 Mhz*
7. Go to **Tools** > **Partition Scheme: "XXXXXX"** and choose *No OTA (Large APP)*
8. Go to **Tools** > **Port: "XXXXXX"** and choose port COM that is connected to ESP32 board. If it is hard for you to decide which one is it, disconnect the board, and check which one of the COM ports disappeared. Connect again and this will be the right port to choose.

Next, download the Augumented_Reality.ino project file.

Open it in Arduino IDE. If prompted that file should be inside a folder of the same name, click yes.

Now there is only one thing that you can or should do. On line 34 there is code that creates name for WiFi access point - `WiFi.softAP("esp-captive");`. Change `esp-captive` it to your desired access point name. If the range of multiple microcontrollers could or will overlap, each one of them requires a unique name.

After that click the round button with right facing arrow **Upload**. This will compile and upload code to the microcontroller.

### 7.4 Using example files

After setting up ESP32, you need to prepare SD card and project files. These instructions present way of editing or creating HTML files that will work directly with the device, without a need to change the C++ code on ESP, and are based on examples provided.

#### 7.4.1 Basic scenarios

##### Text

Create any, simple HTML file. To format it, you can use for example https://html-online.com/editor/. Save it as index.html and place it directly on the SD card.

or

Open index.html file in HTML_examples/Basic_scenarios/text folder with notepad. Edit out *EDIT THIS TITLE*, *EDIT THIS HEADER* and *Lorem ipsum* to your desired text. Save it as index.html. You can add a background file as background.jpg. If you do not add a background file, the background will be black and the text will be white.

Place both index.html and background.jpg (optionally - you can skip this file) directly on the SD card.

##### Image

Use index.html file in HTML_examples/Basic_scenarios/image. Copy it to SD card and add your desired image file, saved in jpg format and name it image1.jpg. The image will be displayed to fill the screen area. The remaining space will black.

You can use Windows Paint or any other graphic editor to save the file as a jpg.

##### Image gallery

Use index.html file in HTML_examples/Basic_scenarios/image_gallery. Copy it to SD card and add your desired image files (maximum of four), saved in jpg format, and named as image1.jpg, image2.jpg, etc. Images will be displayed as 2x2 grid miniatures with a black background. Clicking miniatures will display a full-sized version.

You can use Windows Paint or any other graphic editor to save the file as a jpg.

##### Movie

Use index.html file in HTML_examples/Basic_scenarios/movie. Copy it to an SD card and add your desired movie file in mp4 format and name it movie.mp4. The file will be loaded as a playable movie.

If your movie is not in an mp4 file format, you can use any online video converter, for example, https://www.freeconvert.com/. In the video converters click on to mp4 and upload your video.

##### Sound

Use index.html file in HTML_examples/Basic_scenarios/sound. Copy it to the SD card and add your desired sound file in mp3 format and name it sound.mp3.
You can also add an image (saved as image1.jpg) as a cover photo.
The file will be loaded as a playable sound.

If your sound is not in mp3 format, you need to convert it. Again you can use https://www.freeconvert.com/.

##### Advanced

This example mixes different media types on a single webpage. It includes:
- 5 sections, each with text and header,
- 4 of these sections contain a different image (packed as a single sprite file),
- 1 section with sound,

First, you need to prepare image sprite files. This will include all 4 images for each section within a single file. For this, using any image editor create a single file that is 500x2000 pixels. Save it as image1.jpg. Next prepare four files that you want to use - they need to be square - scale and crop them to 500x500 pixels each. Copy and paste each image to previously created image1.jpg - and paste them from top to bottom, each one under previous. The top image will be displayed under section 1, second under section 2, etc.

Prepare all other media files as described in previous examples.

In the HTML file change all Lorem Ipsum fragments and section titles to your desired descriptions.

Be aware that you are limited to a maximum of 5 files loaded simultaneously. Sometimes event this is not enough to prevent the device from restarting. When using multiple files test the device and keep all files as lightweight as possible.

#### 7.4.2 Gamification

##### Image collecting

This example allows showing a whole image by connecting to six devices. Each device will reveal one part of an image.

Select your image and save it as image1.jpg on an SD card. Copy index.html file from HTML_examples/Gamification/Image_collecting to SD card.

Get next SD card, copy your image and index.html file. Edit html file and on line 9 change from `localStorage.part1 = "1";` to `localStorage.part2 = "1";`

Do the same for the next SD cards, increasing part number on each one until you reach six. Put each SD card in each device and place them in selected locations.

##### XP Collecting

This is a basic example of collecting experience from six different devices. Logging to the first one will award 100 XP points. On 300 points user will reach the next level and be awarded a new avatar with a new description. Reaching 600 points will reach the maximum level with the last avatar.

To use this example first you need to prepare your images. All must be square (1:1 Aspect ratio) with the same resolution. Next prepare the sprite file, by changing the first image vertical resolution to three times its height and then copy each next down under. In other words, prepare a single file out of 3 files by putting them on a grid. For example, if your files are 700x700 pixels, then prepare a file that is 700x2100 pixels, and put the first image so it's left upper corner coordinates would be 0,0, second 0,700, and third 0,1400. Save image as image1.jpg

Now edit index.html file located in HTML_examples/Gamification/XP_collecting. There are a few lines to edit.

On line 68 after line 'document.getElementById("description").innerHTML = ' change text inside quotation marks to you desired description. This is the text for first level. Next do the same on lines 73 and 78 for level second and third respectively.

Copy both image1.jpg and index.html to the first SD card.

Get a second card and again copy both image.jpg and index.html. Edit index.html.

On line 10 change from `if (!localStorage.part1){` to `if (!localStorage.part2){` and on line 25 change from `localStorage.part1 = 1;` to `localStorage.part2 = 1;`.

Do the same for the rest of the SD cards. Put each SD card in each device and place them in selected locations.

##### Riddles

This example uses an image collecting scenario with an added question/answer input form to let users through. After logging into the device user will see a question, input field for an answer, and submit button. After entering the wrong answer (strings are case insensitive), and clicking the "Answer" button text "Wrong answer" will appear below the submit button. On the correct answer, an overlay will disappear and the collected fragment will be shown. It is also spread across 6 devices.

Select your image and save it as image1.jpg on an SD card. Copy index.html file from HTML_examples/Gamification/Riddles to SD card.

Edit index.html and change on line 54 change inside of header `<h1></h1>` to your desired question and on line 11 change `var correct_answer = ""` change to your desired answer.

Get next SD card, make previous changes on lines 54 and line 11 and also on line 19 change `localStorage.part1 = "1";` to `localStorage.part2 = "1";`. 

Do the same for next SD cards, increasing part number on each one until you reach six. Put each SD card in each device and place them in selected locations.

#### 7.4.3 Event scenarios

This example consists of two file types - one index.html is copied on an SD card, the second verification.html is used to check if the generated code is correct.

In each folder (named device_1 to device_4) there is a single index.html. Each file should be copied to a different SD card and placed in a different set.

For each device add one image1.jpg file.

The user after logging into each device will get one portion of a two-digit numeral code. It means logging to all 4 devices will generate a random 8 digit code. After getting all 4 devices script will generate 2 more numbers - these are simple checksum or verification numbers. These last 2 digits are generated based on previous randomly generated digits.

The whole, 10 digit code can be manually transferred to verification.html to check whether the code is correct or not.

Warning - this example is quite easy to hack, it's not encrypted in any way and can be cheated on (by sharing codes). It is recommended not to use this example in money sensitive cases (like merch giveaway, free entries, or discounts). Use it as a scenario example for further development or for digital rewards.

### 7.5 Testing

After modifying and preparing example files put your SD card in the SD card module. Open Arduino IDE (no need to open any file - just start Arduino IDE). Connect microcontroller to your computer and set proper COM port (just like during uploading). Go to **Tools** and choose **Serial Monitor**. In the lower right corner change baud to 115200. Click the reset button on a microcontroller (right between battery and USB connectors). The board should restart and should report it's start up on Serial Monitor.

First, it will report the SD card status. If everything is successful, it should print out files from the SD card. If not, It will report "Card Mount Failed" and restart after few seconds. This could happen just after soldering and first-time use of the SD card and SD card module. Try restarting, plugging, and unplugging the microcontroller, and SD card a few times until it's mounted. After that, there won't be any problem with mounting.

Next microcontroller will start the WiFi access point and report it's IP address that will be 192.168.4.1

Get your phone and connect to a WiFi network created by a microcontroller. In your browser enter 192.168.4.1 and see if your webpage is working the desired way.

If there are some problems with a webpage, you are using any collecting scenarios and you want to go back to the primordial state (just like freshly connecting new phone) clean cookies and web stored pages in your smartphone.

### 7.6 Assembling case

1. Guide USB wire through the opening in the bottom case.

Case assembly

2. Put two pieces of 3d printed stoppers around the cable. You can do it from inside (more secure, but a bit tricky) or from the bottom.

Case assembly

3. Place Lolin board in it slot, connectors upward, with electronics facing batteries compartment. Next put the microSD card module in its slot, again with electronics facing the batteries compartment. After this, connect micro-USB to the Lolin board, and pull it down so there is no loose cable in the compartment.

Case assembly

4. Put batteries in the battery compartment, and connect wires to battery socket on Lolin board.

Case assembly

5. Insert the microSD card in the microSD card module. You can store extra microSD cards in side compartments.

Case assembly

6. Cover all with the top piece of 3D printed case. Correct wires guiding if the case can't close completely.

Case assembly

7. Use a zip tie to secure both parts of the case. You can use side handles to zip tie the case to environmental elements like tree branches or poles.

Case assembly

## 8. Notes

- all files used in HTML examples are licensed under CC-0 licenses.
- while creating HTML pages, you cannot use more than 5 files that are loaded at the same time. If you need to load more files you can:
    - use css image sprites,
    - include styles inside index.html
    - pack scripts into single gz files or include them in the index.html file.
- keep all media as lightweight as possible - transfer rates are not great and sometimes even image sprites are not enough to prevent device restart during download.
- event example is quite easy to hack, it's not encrypted in any way and can be cheated on (by sharing codes). It is recommended not to use this example in money sensitive cases (like merch giveaway, free entries, or discounts). Use it as a scenario example for further development or for digital rewards.

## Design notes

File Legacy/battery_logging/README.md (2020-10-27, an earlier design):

## Battery logging

Code for logging battery voltage to google sheets.

Based on:

https://randomnerdtutorials.com/esp32-esp8266-publish-sensor-readings-to-google-sheets/

https://www.youtube.com/watch?v=5JIJO1swQPE

*UPDATE: It turns out that you need to connect input to pin that works on ADC1 not ADC2. After initialising WiFi all analog Read from ACD2 will have value of 4095. It works ok on ADC1.*

*UPDATE: For 4.12V on battery ESP reports 2512, for 3.84V it reports 2261. It can be used to plot voltage in time instead of just reported value.*

This setup will check basic battery life when not connected to any power source other then batteries (dual 18650). It writes data every 15 seconds to simulate heavy load.

Second circuit includes solar panel. It's located outside, in indirect sunlight, with only one battery, and reports it's status every minute. It reports both battery level and solar panel voltage.

*UPDATE: 3.64V of solar equals 1750. 0.65V equals 225.

### Setup
Few thing must be done to log data.
1. Available WiFi with connection to internet.
2. Created account and webhooks applet on IFTTT.
3. Physical connetions according to scheme.
4. Changed code (WiFi credentials and IFTTT URL resource).

### Connection diagram for battery test

Battery logger diagram

### Connection diagram for solar test

Solar logger diagram

### Basic operation

After powering up, ESP connects to local Wifi (predefined). After connecting it connenects to IFTTT and sends recived data from analogRead(). Next, IFTTT publish this data to google sheets with date, time and value.

Code will send direct analogRead() values to google sheet. Before connecting to IFTTT service, it will check if board is conneted to WiFi. If not, it will try to connect.

### Outcome

#### Dual 18650 battery without solar power with high load (4850 connection per day)

Graph

Test of only battery powered solution with high load (connection every 15 seconds) gave final working time of almost 29 hours.
It started at 3,98 V and finally droped to 3,08V before finally turning off. After connecting to power source it immediately reconnected and continued to send data to IFTTT service.

#### Dual 18650 battery without solar power with low load (96 connection per day)

Graph

Test of only battery powered solution with low load (around 100 visitors per day - one every 15 minutes).
Test gave similar results in terms how voltage acts, but electronics were turned on for 9 hours shorter when compered to high data logging. One more test with same enviroment is needed to check if these are working conditions, or it's batteries deterioration.

Another test showed that batteries lasted for over 39 hours. We can se on graph, that first test, had drastic drop in voltage at beggining. It suggest that batteries ware not fully loaded.

#### Compared results 

Graph

#### Single 18650 battery with 2W solar panel in shade

Graph

Leaving solar panel in shade is not effecient. Single battery was enough for around 13 hours of work. Solar panel didn't do much, you can see that after dark (when solar panel voltage droped to zero) there was speed up in battery discharge, but it is similar to drop in case without solar power.. Probably 3,6V is not enough to load the battery.

Battery died around 2:00, and stayed off until next day morning sun hit solar panel directly. It lasted for arround hour of low power supply (top voltage on this solar panel is 7.2V while top value recorded was 4V), unitl it got into shade again, and supplied battery with power to last another hour.

#### Single 18650 battery with 2W solar panel in direct sunlight

Graph

Device was placed outside (discharged) at around 2:00. It was left for the night and next checked ar 14:00. It has turned on due to power from solar panels, but it has not connected to wifi (probably low reception). After bringing it in to connect and later leaving outside it was working fine. Graph clearly shows when it became shaded and when night began. Next day we see when sun rose, then when it hit panel directly. It's was mild day with heat wave around 13:30 after which there was thunderstorm. Device was left outside. Next day was mild, up until 14:00 when it started raining. Device died around 2:30 and have not powered up, since it is still raining and there is no sun.

#### Conclusion

Even with solar power, due to mixed atmospheric condidtions, it is need to supply device with minimum 2 batteries.

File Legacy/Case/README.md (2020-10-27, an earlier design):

## CASE



RENDER

Main assumptions:
- weather resistance as IP33 - when mounted upright, electronics will be protected against rain and dust. Weak point is cable passtrough. It is left big to pull micro USB connector without need to cut the wire. It can be upgraded to IP68 by using silicone.
- hard case - all walls are thick so it will protect electronics from phisical damage
- steady mounting - batteries and ESP will have minimal movement to minimalize disconnetions and shortcuts.
- closing should be as simple as possible - no screws or mechanisms - joining part would be acomplished by zip ties.
- low eastetics - case is not supposed to be pretty - it's always hidden and do not require to look good. It should be functional.
- 3D printable - can be printed without advanced slicing - no supports, overhangs and so.

Added second version of case that can house 4 batteries - in case device will operate only on batteries (without solar or power supply) it will increase it's working time up to 80 hours (over 3 days).

*EDIT:* File for 4 batteries case is the same as for 2 batteries. It's a mistake, need to upload correct one.

TODO:
- ~~change rotation of up arrow on upper case~~
- ~~thicken lower part for more stability and better looks.~~
- ~~add mounting hook~~
- ~~round lower case outer edge (top one)~~
- ~~modify compartment for batteries (more space, and separation from module).~~
- ~~smaller stopper inserting side, bigger base~~
- ~~round stoppers~~
- ~~remove chamfer in upper part~~
- ~~increase zip tie slot width and depth.~~
- ~~change zip tie slot to chamfer, not round.~~
- add compartment for SD reader
- modify compartment for ESP to enable connections to SD reader

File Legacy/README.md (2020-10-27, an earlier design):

## Zamówione komponenty:

##### ESP:
https://allegro.pl/oferta/esp32-lite-4mb-flash-wifi-bluetooth-lolin32-8644932107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

alternatywa Ali (przetestowana)

https://www.aliexpress.com/item/33006577783.html?spm=a2g0s.9042311.0.0.4f6f4c4dRUueju

##### Koszyczki pod baterię:
https://allegro.pl/oferta/koszyk-pojemnik-uchwyt-na-1x-18650-ogniwo-3164-9423389445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

##### Baterie - wychodzi na to że mają maksymalnie 1800 mAh. Można podciągnąć do góry wydajność kupując firmowe np. sony 2250 mAh:
https://allegro.pl/oferta/akumulator-bateria-4800mah-18650-li-ion-3-7v-szare-9260214771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

##### Ogniwo słoneczne:
https://allegro.pl/oferta/ogniwo-sloneczne-fotowoltaiczne-2w-6v-os2-pv-9325281596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

alternatywa Ali - przetestowane - maks 100mA, nie nadają się na ten projekt. Trzeba kupić większe.

https://www.aliexpress.com/item/33007861569.html?spm=a2g0s.9042311.0.0.4f6f4c4dRUueju

##### USB: (do rozcięcia do zlutowania z ogniwem)
https://allegro.pl/oferta/kabel-do-ladowania-micro-usb-2a-szybkie-ladowanie-8927500521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

##### czytnik kart microSD - zły - mimo że opisany jest jako pracujący na 3.3V to działa tylko na 5V. Zamówiony drugi. Drugi okazał się być czytnikiem SD a nie microSD. Zamówiony trzeci i w końcu trafiony. Tylko już niedostępny na allegro.

https://allegro.pl/oferta/modul-czytnik-kart-microsd-micro-sd-arduino-avr-fv-7587212548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

https://allegro.pl/oferta/czytnik-kart-sd-interfejs-spi-arduino-9608972332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

##### karty microSD (różne pojemności)
https://allegro.pl/oferta/karta-pamieci-microsd-1gb-sdhc-micro-sd-gw-fv-8995743207

https://allegro.pl/oferta/karta-pamieci-microsd-2gb-sdhc-micro-sd-gw-fv-7950284934

https://allegro.pl/oferta/karta-pamieci-4gb-micro-sd-microsd-sdhc-fv-gw-7814324566

https://allegro.pl/oferta/karta-pamieci-microsd-8gb-sdhc-gwarancja-fv-7643739086

https://allegro.pl/oferta/karta-pamieci-microsd-16gb-sdhc-gwarancja-fv-7643757943

## Bazowe założenia
Główną ideą całego projektu jest jego udostępnienie na zasadach licencji CC-BY. Założenie takie generuje pewne cechy produktu, które muszą zostać jak najlepiej spełnione, aby projekt miał sens. W przeciwnym wypadku urządzenie to nie będzie miało możliwości zostać użyte poza projektem „Rozszerzona Rzeczywistość”.

### 1.	Łatwość konfiguracji i montażu
Pierwszym założeniem dla projektu jest możliwość realizacji scenariusza i produkcji urządzenia przez jak największą liczbę osób lub instytucji. Ze względu na to, że wielu z potencjalnych przyszłych użytkowników nie posiada umiejętności technicznych, główną ideą jest zapewnienie jak najmniejszego stopnia skomplikowania.

Docelowym pomysłem jest używanie gotowych modułów, nawet kosztem wydajności energetycznej rozwiązań (gotowe moduły zamiast indywidualnej budowy komponentów). W miarę możliwości najlepszym rozwiązaniem była by możliwość zaprojektowania systemu który można podłączyć na zasadzie „pająka” bez potrzeba tworzenia płytek prototypowych czy nawet lutowania.

Tak samo zaprogramowanie urządzenia powinno być jak najłatwiejsze. W najprostszym scenariuszu użycia powinno pozawalać na postępowanie krok po kroku za instrukcją, bez jakiejkolwiek wiedzy z zakresu stosowanych rozwiązań, aby pozwolić jak największej ilości osób na wykorzystanie urządzenia.

### 2.	Cena
Bazowe założenia uwzględniają również cenę gotowego urządzenia. Docelowy koszt produkcji rzędu kilkuset złotych zdecydowanie ograniczy liczbę zastosowań. Produkcja 5 urządzeń w cenie np. 500 zł będzie kosztem nieakceptowalnym dla indywidualnego artysty oraz bardzo nieciekawą opcją dla mniejszych festiwali, ponieważ pieniądze takie można zainwestować w lepszy sposób.

### 3.	Dostępność komponentów
Wszystkie komponenty użyte w projekcie powinny w miarę możliwości posiadać alternatywę, oraz przede wszystkim być powszechnie (również branżowo) dostępne. Projekt wyklucza używanie nietypowych i rzadkich komponentów.

### 4.	Scenariusz user-friendly
Poza kwestiami związanymi z produkcją i wdrożeniem rozwiązania dla organizatorów wydarzeń, w scenariuszach użycia oraz scenariuszach funkcjonalno-użytkowych należy założyć jak najprostszą ścieżkę dla użytkownika końcowego – korzystnie z urządzenia musi być łatwe i nie angażujące, ponieważ projektowane urządzenie i scenariusze są tylko narzędziem do przekazywania treści, a nie treścią samą w sobie.
Najlepszym rozwiązaniem będzie ograniczenie interakcji docelowego użytkownika/zwiedzającego do podłączenia się przez bluetooth/wifi, włączenia aplikacji (lub przeglądarki) oraz ewentualne naciśnięcia jednego przycisku.

### 5.	Uniwersalność instalacji
Pomysł zakłada jak najszersze użycie urządzenia. Dlatego projekt techniczny powinien zakładać jak najwięcej możliwości montażu oraz zasilania urządzenia.
Scenariusz użycia powinien być natomiast na tyle elastyczny, aby móc spełnić jak najwięcej wymagań organizatora.

### 6.	Kwestia modułowości
Dobrym założeniem - chociaż nie koniecznym, jest analiza możliwości stworzenia urządzenia modułowego – tak by w zależności od potrzeb można było rezygnować z niektórych komponentów w celu ograniczenia kosztów, jednak rozwiązania modułowe są znacznie trudniejsze w realizacji i pomysł ten może być za skomplikowany, biorąc pod uwagę dostępne zasoby czasowe.
 
## Urządzenie

### 1.	Bazowy mikrokontroler
~~Na ten moment projekt bazuje na module ESP32-WROOM w wersji płytki prototypowej LOLIN32. Posiada ona pełną funkcjonalność płytki ESP32-WROOM z dodatkową bardzo atrakcyjną funkcją wbudowanego kontrolera ładowania baterii 18650.
Poza tym posiada (co istotne z punktu widzenia projektu):~~
- ~~moduł Wifi~~
- ~~moduł Bluetooth~~
- ~~4 MB pamięci Flash~~

~~Drugą opcją jest użycie Raspbbery Pi Zero W. Trudniejsza podłączenie elektroniki, wyższa cena, ale za to znacznie łatwiejsza konfiguracja Captiver Portal, Wifi AP, oraz większe możliwości stworzenia strony Captive portal (normalny dostęp do kart SD).~~

Rozważone zostały dwa rozwiązania. Pierwsze bazowało na układzie mikrokontrolera z modułami WiFi, drugie natomiast na bazie mikrokomputera Raspberry Pi.

Po wstępnym przeglądzie dostępnych rozwiązań do testów trafiły poniższe urządzenia:
- mikrokontroler WEMOS Lolin32 Lite
- Raspberry Pi Zero W

Porównanie obu rozwiązań poniżej:
| Element | Lolin32 Lite | +/- | Raspberry Pi Zero W | +/- |
| --- | --- | :---: | --- | :---: |
| Cena zestawu | ~70 zł w polsce, ~45 zł aliexpress (wersja kompletna z zasilaniem solarnym) | + | ~150 zł (brak zamienników) | - |
| Urządzenia alternatywne| dostępne | + | brak innych rozwiązań | - |
| Dostępność | globalna, w wielu sztukach | + | globalna, jednorazowo można kupić tylko 1 sztukę | - |
| Moduły | Wifi i Bluetooth | + | Wifi i Bluetooth | + |
| Pobór mocy | 80 mA w trybie czuwania, 150 mA w transmisji WiFi | + | 250 mA | - |
| Wymiary | 50 x 25 x 7 mm | + | 65 x 30 x 5 mm | - |
| Obsługa HTTPS | nie | - | nie | - |
| Pamięć | 4 Mb lub zależna od karty SD | + | Zależna od karty SSD | + |
| Łatwość złożenia | średnia | +/- | wysoka | + |
| Łatwość pierwotnej konfiguracji | wysoka | + | niska | - |
| Łatwość rekonfiguracji | niska | - | wysoka | + |

Wynikiem analizy powyższych elementów jest decyzja o kontynuacji projektu bazując na module Lolin32. Mimo małej ilości dostępnej pamięci, trudniejszej rekonfiguracji i nieco większej fizycznej złożoności, moduł ten zdecydowanie lepiej spełnia pierwotne założenia projektu.

### 2.	Zasilanie bateryjne
Mimo zasilania przy pomocy ogniw słonecznych wymagane jest również zasilanie urządzenia przy pomocy baterii. Zarówno w celu stabilizacji napięcia zasilającego, jak również w celu zapewnienia zasilania w przypadku złej pogody lub wieczora/nocy.

Po wstępnej analizie rozwiązań i doborze mikrokontrolera wybór pada na baterie 18650. Posiadają dużą pojemność, odpowiednie napięcie zasilania oraz przede wszystkim mikrokontroler posiada wbudowany układ ładowania tego typu baterii.

Przeprowadzone testy pokazały, że moduł może być zasilany z baterii 18650 z dużą skutecznością. W przypadku zasialania z dwóch takich baterii, możliwe jest osiągnięcie czasu pracy na poziomie 40 godzin. Każda kolejna bateria dodana do zestawu przedłuża czas pracy urządzenia. Dlatego w przypadku w przypadku zasilania tylko z baterii, stworzona została dodatkowa obudowa na 4 baterie.

### 3.	„Eko” zasilanie
W celu zapewnienia pracy ciągłej urządzenia oprócz baterii należy rozważyć zasilanie urządzenia przy pomocy odnawialnych źródeł energii (jest to pojęcie mocno na wyraz w przypadku tego projektu). W każdym razie zakładamy autonomiczną pracę urządzenia, więc należy zadbać o możliwość zasilania urządzenia w inny sposób niż tylko bateryjny lub sieciowy.

Na dzień dzisiejszy mamy dwie możliwości – energia solarna lub wiatrowa. Inne opcje są wyjątkowo skomplikowane i poza spektrum tego projektu.

Szukając rozwiązań dostępnych w internecie można zauważyć że energia solarna jest tania i prosta w implementacji. Natomiast energia wiatrowa nie jest nigdzie opisana i jest to rozwiązanie bardzo prototypowe które może być nieskuteczne i drogie.

W takim wypadku skupiłbym się na użyciu tylko i wyłącznie paneli słonecznych w celu zasilenia urządzenia.

Kwestią którą trzeba rozwiązać jest również zasilanie z trzech źródeł – sieciowe, bateryjne i solarne. Na ten moment widziałem tylko projekty które brały pod uwagę zasilanie solarno/akumulatorowe, jednak ze względu na założenia bazowe trzeba zaimplementować możliwość zasilania sieciowego.

### 4.	Inne komponenty
Dodatkowe komponenty nie muszą zostać użyte w aktualnym projekcie ze względów takich samych jak stworzenie modułowego rozwiązania – czyli ograniczenia czasowe.

Komponenty te jednak w najlepszej opcji bazowały by na idei modularności – ze względu na zwiększenie ceny gotowego urządzenia. Na ten moment można pokusić się o założenie że te są to opcje które mogą być zaimplementowane w wersji 2.0, jednak wzięcie ich pod uwagę na tym etapie projektu daje ułatwia drogę do ich dalszego rozwoju.

#### a)	Wyświetlacz
Dodanie modułu wyświetlacza pozawala w pewien sposób odciążyć merytoryczne połączenie urządzenie-telefon. Użycie dowolnych modułów wyświetlaczy (alfanumeryczny, LCD, OLED) pozwoli na przestawienie treści bez angażowania technologicznego zwiedzającego. Możliwe również jest stworzenie autonomicznego punktu wykorzystującego ideę scenariuszy podstawowych gdzie w ograniczonej formie można przekazać dodatkową treść do prezentowanego dzieła.

#### b)	Głośnik
Rozwiązanie to jest tożsame z wykorzystaniem wyświetlacza, jednak wykorzystuje zmysł słuchu w celu przekazania dodatkowych informacji.

Dodatkowo możliwe jest użycie głośnika w celu cyklicznego odtwarzania dźwięków które może posłużyć jako dodatkowa forma gamifikacji – poszukiwanie miejsca prezentacji bazując na słuchu (np. w obszarach o dużej przestrzeni jak parki czy lasy).

## Podstawowa funkcjonalność urządzenia
Bazując na podstawowych założeniach chcemy osiągnąć produkt który będzie łatwy i w miarę możliwości nieskomplikowany w obsłudze dla końcowego użytkownika. Również musimy mieć na względzie możliwości organizatorów – czyli ograniczenia technologiczne i budżetowe.

~~Ogólnie można przyjąć dwie drogi postępowania – po podłączeniu do urządzenia i włączeniu aplikacji użytkownik może otrzymać dwa rodzaje treści:~~
- ~~docelową treść którą chce przekazać artysta/organizator~~

- ~~treść tekstową~~

~~Mówiąc dowolna treść mam na myśli treść multimedialną – film, zdjęcie, tekst.~~

~~Pierwsze rozwiązanie jest znacznie lepsze dla odbiorcy końcowego, jednak myślę że jest wyjątkowo kłopotliwe dla twórcy. Po pierwsze przekazanie takiej treści na pewno wymagać będzie zaawansowanej wiedzy z zakresu programowania aplikacji, ponieważ każde zastosowanie wymagać będzie napisania od nowa algorytmu który będzie obsługiwać backend komunikacji. Nie wspominając o ile trudniejsze będzie zastosowanie rozwiązania w przypadku bardziej skomplikowanych scenariuszy np. gamifikacyjnych. Dodatkowo rozwiązanie to sprawi że każda wystawa lub festiwal będzie musiał udostępnić własną aplikację tylko w celu obsługi eventu.~~

~~Drugie rozwiązanie jest mniej przyjazne dla użytkownika końcowego (ale też nie wymaga żadnej wiedzy technicznej), ale wyjątkowo proste dla organizatora. Przesyłana po bluetoothie wiadomość jest tylko treścią tekstową. Może to być dowolna treść – w najprostszym przypadku link do strony www – dzięki czemu artyści/organizatorzy którzy dysponują ograniczonym budżetem i/lub umiejętnościami w zakresie programowania mogę udostępnić link do dowolnej strony od social mediów, przez youtube po prosty link do grafiki czy nawet kod zniżkowy na wstęp na festiwal. W bardziej zaawansowanych przypadkach znacznie tańsze i łatwiejsze jest stworzenie prostej witryny która udostępnia stopniowo treści, niż stworzenie aplikacji na wiele systemów o takiej samej funkcjonalności.
W związku z tymi rozważaniami uważam że opracowane urządzenie powinno wysyłać tylko treść tekstową, co pozwoli na ułatwienie użycia dla większej ilości osób lub podmiotów.~~

W wyniku ustaleń bieżącym rozwiązaniem jest zastosowanie funkcjonalności captive portal. Podłączenie do urządzenia odbywać będzie się po sieci WiFi (nie bluetooth), dzięki czemu wystarczy zalogować się do wskazanej sieci, gdzie po podłączeniu użytkownik zostanie automatycznie przekierowany (lub będzie musiał wpisać konkretny adres w przeglądarce - zależne to będzie od telefonu użytkowanika - w wyniku bieżących testów część telefonów wyświetla od razu notyfikacje zaloguj się do sieci wifi, która przekierowuje od razu do webserwera, część natomiast nie) aby dostać się na stronę html (znajdującą się lokalnie na urządzeniu). Rozwiązanie to zmniejsza dostępny stopień skomplikowania strony (również przez ograniczenia ilości miejsca - maks 4 mb), jednak całkowicie wyklucza potrzebę instalacji specjalnej aplikacji (przez odbiorcę) lub jej stworzenia/napisania (przez organizatora). Również dzięki temu projekt staje się niezależnym nośnikiem treści, a nie tylko przekierowaniem dla niej (eliminując skojarzenia z pewną formą mniej przystępnego QR kodu tylko w wersji cyfrowej).

## Scenariusze użycia

Schemat

### 1.	Scenariusze podstawowe
Scenariusze podstawowe opisują najprostsze i najbardziej standardowe formy użycia. Dają dodatkowe możliwości przekazu treści, w sytuacjach które ograniczają media dotychczas stosowane.

#### a)	Zwiedzanie rozproszone
Usytuowanie wielu (lub nawet jednego urządzenia) w dowolnej lokalizacji (przestrzenie publiczne, sklepu, bary, restauracje), pozwoli na przekazanie docelowej treści bez gromadzenia osób w jednej przestrzeni. Korzystając z mediów społecznościowych możliwe jest udostępnienie lokalizacji w których znajdować będą się urządzenia, docierając w sposób pośredni do potencjalnych odbiorców. Rozwiązanie pozwala zachować wszystkie zalecenia dotyczące dystansu społecznego (w obecnej sytuacji) oraz daje dodatkowe możliwości przekazu który nie jest ograniczony ze względu na przestrzeń.
Nawet w przypadku wystawy zlokalizowanej w jednym miejscu zastosowanie rozwiązania daje dodatkowe możliwości w postaci udostępnienia treści w innych regionach miasta, kraju a nawet świata (wystawa odbywająca się w jednym mieście może mieć odbiorców na całym świecie).

#### b)	Komentarz merytoryczny
O ile w przypadku wystaw w galeriach opis czy komentarz merytoryczny jest możliwy do powieszenia obok dzieła, to w większości przypadków gdy dzieło prezentowane jest w przestrzeni publicznej takie możliwości są ograniczone lub całkowicie nie realizowalne. Montaż urządzenia w okolicy instalacji/mappingu/muralu daje możliwość przekazania dodatkowych informacji dla osób które są zaciekawione czymś więcej niż samą formą lub prezentacją dzieła.

#### c)	Rozszerzona ścieżka zwiedzania
Urządzenie można zastosować również dodatkowe medium do przekazania treści. W przypadku indywidualnych artystów, którzy nie są tylko skupieni na jedniej formie, pozwala to udostępnić zwiedzającym dodatkową treść w postaci dzieł których prezentacja w klasycznej, fizycznej formie jest niemożliwa ze względu np. na ograniczenia przestrzenne, lub finansowe.
Festiwale mogą w ten sposób prezentować dodatkowe treści które standardowo nie są atrakcyjne dla zwiedzających oczekujących wrażeń wzrokowo- słuchowych. Związane z tematyką festiwalu w rozszerzonej ścieżce zwiedzania obok obrazów/rzeźb/zdjęć/instalacji mogą pojawić się wiersze czy fragmenty opowiadań.

### 2.	Scenariusze gamifikacji
Scenariusze gamifikacji mają na celu uatrakcyjnienie odbioru treści prezentowanych przez artystę/organizację. Są elementem pośrednim między klasycznym marketingiem a niekomercyjną promocją. Pozwalają również na rozciągnięcie w czasie wydarzenia, co może mieć zastosowanie w przypadku indywidualnych twórców planujących większe wydarzenia, jak i dla organizacji chcących zwiększyć aktywność uczestników w planowanych festiwalach. Scenariusze gamifikacji również są rozszerzeniem dla standardowych możliwości podstawowych scenariuszy zwiedzania. Użycie scenariuszy gamifikacji wymaga zastosowania zewnętrznych form przekazu informacji (np. media społecznościowe).

Pierwszym założeniem technologicznym dla scenariuszy gamifikacji, przy użyciu Captive portal jest zastosowanie plików cookies. Będziemy logować się za każdym razem tak naprawdę na tą samą stronę, z tym samym adresem, więc zapisane pliki coockies powinny działać mimo łączenia się do różnych urządzeń. Problemem może być ESP - posida bardzo ograniczone możliwości przesyłu stron WWW.

Druga opcja to rozwiązanie scenariuszowe polegające np. na zbieraniu kodów. Każdy kod zebrany udostępnia kolejną część na zewnętrznej stronie WWW.

#### a)	Zbieranie kolekcji
Scenariusz ten zakłada dodanie atrakcyjnego elementu zbierania różnych dzieł aby utworzyć kolekcję. Bazuje on na grach komputerowych w których jest stały element przedłużający rozgrywkę. Jest na tyle atrakcyjne rozwiązanie że znalazło zastosowanie w funkcjonowaniu miejsc pracy. Organizator udostępniając w mediach społecznościowych kolejne lokalizacje urządzeń angażuje zwiedzających do aktywnego uczestnictwa w wydarzeniu. Scenariusz ten zakłada odwiedzanie miesc wskazanych przez organizatora, w celu zebrania kolejnych (w bazowym założeniu) dzieł, aby na koniec mieć dostęp do całości wystawy.

#### b)	Komponowanie dzieła
Jest to alternatywa dla zbierania kolekcji. Wymaga większego wkładu technologicznego w celu zaprojektowania rozwiązania. Bazuje nie na zbieraniu poszczególnych dzieł, ale na składaniu jednego kompletnego dzieła przez odwiedzenie poszczególnych miejsc wskazanych przez organizatora. Docelowo może to być złożenie obrazu z fragmentów, zebranie całości filmu lub opowiadania.

#### c)	Geocatching
Jest kolejnym rozszerzeniem poprzednich opcji. W tym przypadku zbieranie kolekcji lub fragmentów odbywa się w duchu geocatchingu. Organizator udostępnia w wybranych przez siebie mediach kolejne koordynaty geograficzne, lub nawet same zdjęcia lokalizacji, w celu zaanagażowania uczestników w ich znalezienie. Udostępniane lokalizacje mogą mieć charakter typowo komercyjny (lokalizacje współpracujących galerii lub innych podmiotów) jak i merytoryczny (miejsca powiązane z tematyką dzieła).

### 3.	Scenariusze eventowe
Scenariusze eventowe są skierowane głównie do festiwali w celu dodania dodatkowych narzędzi marketingowych oraz większego zaangażowania uczestników festiwalu. Scenariusze eventowe są dalszym rozszerzeniem scenariuszy gamifikacji. Opierają się głównie na tych samych technikach, jednak ich cel ma znaczenie bardziej komercyjne.

#### a)	System zniżek

Zastosowanie scenariuszy gamifikacji, przy zaangażowaniu dodatkowych środków pozwala na użycie tych scenariuszy w sposób czysto komercyjny. Znalezienie wszystkich elementów dzieła lub kolekcji generuje kod który uprawnia do zniżki np. na wejście na główne wydarzenie.

#### b)	System VIP

Rozwiązanie to tyczy się głównie festiwali muzyczno-artystycznych. Wykonanie zadań przewidzianych w scenariuszach gamifikacyjnych uprawnia do otrzymania wstępu VIP – dostępu na backstage oraz innych przywilejów z tym związanych – oczywiście zakres zależny jest od organizatora oraz artystów.

#### c)	Mechanizm losowania

Nadrzędnie, w przypadku gdy możliwości organizatorów są ograniczone, możliwe jest zastosowanie systemu losowania, gdzie realizacja formy zbierania elementów uprawnia do udziału w losowaniu dla wyżej wymienionych systemów.

## Oprogramowanie

### 1.	Podstawowy dostęp
Na ten moment podstawowym założeniem dostępu do treści jest stworzenie funkcjonalności captive portal. Łącząc się z modułem przez Wifi, wpisując dowolny adres w przeglądarce użytkownik zostanie przekierowany do webservera umieszczonego na płytce.

##### a) ESP
https://www.youtube.com/watch?v=AHO1zN8c_zU
~~problem - z komentarzy wynika że ten captive portal nie przekierowuje z https, tylko z http. Więc wpisanie czegokolwiek w przeglądarkę automatycznie przekieruje na google które jest na https. Problem do rozwiązania technologicznego (dodanie obsługi https) lub scenariuszowego (wpisanie konkretnego adresu w przeglądarkę)~~

~~Pozwoli to na przekazanie dowolnej strony web. Ze względu na założenie że po podłączeniu do wifi urządzenia nie mamy dostępu do internetu możemy przekazać stronę web w najprostszej tekstowej postaci.~~

*EDIT* Captive portal na ESP nie pozwala na przekierowanie z adresów HTTPS. Większość adresów współcześnie to HTTPS. W niektórych telefonach po podłączeniu do WiFi urządzenia automatycznie pojawi się strona captive portal, ale nie jest to standardem. Dodanie funkcjonalności obsługi Captive portal na ESP to zadanie zdecydowanie zbyt zaawansowane na ten projekt. Dlatego po zalogowaniu się do sieci użytkownik będzie musiał wpisać konkretny adres w przeglądarkę.

~~#### b) RPi Zero W~~
~~https://www.maketecheasier.com/turn-raspberry-pi-captive-portal-wi%E2%80%90fi-access-point/~~

~~*EDIT* Testy pokazały że capitve portal na RPI też nie przekierowuje z HTTPS.~~

Nie stosuje RPi.

### 2.	Obsługa zdjęć
#### a) ESP
~~Tutaj jest pewien problem. Jak do tej pory nie znalazłem żadnego rozwiązania pozwalającego na pobieranie obrazów z zewnętrznej karty SSD. Można zapisać pliki w postaci SPIFFS ale ogranicza to rozmiar całości projektu (razem z obrazami do 4 MB). *EDIT* Sprawdzone - na ten moment należy ograniczyć rozmiar strony wraz z mediami do 4MB na urządzenie.~~

~~Ograniczenia są jednak większe. Płytkę w Arduino IDE należy wybrać nie WEMOS lolin32 tylko ESP32 DEV module i następnie z partition wybrać układ 1mb na program i 3 mb na SPIFFS. wtedy dostępne jest 3 mb na pliki webserwera.~~

~~https://randomnerdtutorials.com/display-images-esp32-esp8266-web-server/~~

~~Wygląda na to że ograniczenie pamięci jest jednak dużo większe niż 4mb, będzie to jeszcze weryfikowane. Dodatkowa kroki to użycie karty SD które może okazać się znacznie łatwiejsze niż wydawałoby się na początku:~~

~~https://randomnerdtutorials.com/build-an-all-in-one-esp32-weather-station-shield/~~

~~Jednak nie jest to takie łatwe. Mam biblioteki które obsługują async webserver z karty sd, ale przykład nie działa, nie ma dokumentacji a kod jest wyjątkowo skomplikowany:~~

~~https://github.com/paidforby/AsyncSDServer~~

Opanowane. Obsługa zdjęć z karty SD działa poprawnie. Pojawiło się za to nowe ograniczenie. Jest limit jednoczesnych podłączeń SPI. Maksymalnie można łączyć się z 5 plikami jednocześnie. Utrudnia to tworzenie większych stron ale jest parę rozwiązań:
- skrypty można zapisywać w pliku HTML lub pakować je w .gz
- style można umieszczać w pliku html zamiast w osobnym css
- pliki graficzne można obsługiwać jako css image sprites
- można budować wielopoziomowe strony (do przetestowania)

~~#### b) RPi~~
~~Brak jakiegokolwiek problemu - wrzucamy dowolną stronę WWW która działa jako captive portal z dowolnymi elementami.~~

Nie stosuje RPi.

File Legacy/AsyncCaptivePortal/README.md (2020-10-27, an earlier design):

### Asynchronous Web Server with captive portal and data stored in SPIFFS

This code acts as asynchronous webserver, with http redirection (Captive Portal).

HTML page and images are stored in ESP32 flash memory as SPIFFS files.

#### Code

Required libraries

    #include <WiFi.h>
    #include <DNSServer.h>
    #include <ESPAsyncWebServer.h>
    #include <SPIFFS.h>

Setting up DNS server

    const byte DNS_PORT = 53;
    IPAddress apIP(192, 168, 1, 1);
    DNSServer dnsServer;

Starting asynchronous web server on port 80

    AsyncWebServer server(80);

Starting Wifi as access point, with IP and name

    void setup() {
      WiFi.mode(WIFI_AP);
      WiFi.softAPConfig(apIP, apIP, IPAddress(255, 255, 255, 0));
      WiFi.softAP("CaptivePortal 5");

Starting dns server. "*" will redirect all http trafic to local server

      dnsServer.start(DNS_PORT, "*", apIP);

Starting SPIFFS

      if(!SPIFFS.begin()){
            Serial.println("An Error has occurred while mounting SPIFFS");
            return;
      }

Redirecting all requests of asynchronous server to SPIFFS memory.

      server.on("/", HTTP_GET, [](AsyncWebServerRequest *request){
        request->send(SPIFFS, "/index.html", String(), false);
      });
      server.on("/sun", HTTP_GET, [](AsyncWebServerRequest *request){
        request->send(SPIFFS, "/sun.png", "image/png");
      });
      server.on("/sun-cloud", HTTP_GET, [](AsyncWebServerRequest *request){
        request->send(SPIFFS, "/sun-cloud.png", "image/png");
      });
      server.on("/cloud", HTTP_GET, [](AsyncWebServerRequest *request){
        request->send(SPIFFS, "/cloud.png", "image/png");
      });
      server.on("/rain", HTTP_GET, [](AsyncWebServerRequest *request){
        request->send(SPIFFS, "/rain.png", "image/png");
     });
      server.on("/storm", HTTP_GET, [](AsyncWebServerRequest *request){
        request->send(SPIFFS, "/storm.png", "image/png");
      });
      server.on("/snow", HTTP_GET, [](AsyncWebServerRequest *request){
        request->send(SPIFFS, "/snow.png", "image/png");
      });
      server.begin();
    }

Handling clients

    void loop() {
      dnsServer.processNextRequest();
    }

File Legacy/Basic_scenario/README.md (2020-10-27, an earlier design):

# Basic scenarios

Basic scenarios are first step of delivering concent to recipent.

## Scenarios

Three subscenarios can be included in it's usage:

### 1. Substantive comment

This scenario allows to add extended explanation, comment, history fact, author biography to presented art piece, when no other forms are available. It would apply mostly to historical points, big scale installations, urban art, murals, or mappings, where scale or location do not allow to add printed description, or it would be easly missed.

Examples of usage:

- big scale mural, placed in urban enviroment, have no way of including informations about artist and/or comment about painting itself. Even if there is possible way to place it, with such scale it will be missed by visitors, that will take some space between facade and viewing area. Connecting to device will allow them to get these extra information on thier phones.
- placing informational boards on historical building or monuments is not possible. Device placed in it's close perimeter whill allow to share facts, photos ot other extra information about it's origin.
- large scale installation or videomapping during festival will be hard to to comment, or at least present the author, because any informational slate will be lost in it's scale. Using device will allow to deliver all information that could be shared, like artist bio, commentatory, photos or movies of construction etc.

### 2. Scattered content

Scattering content allows to take art outside of exhibitions area. Multiple devices located in different places (within city, country or even globally), allows to scatter visitors and apply more social distancing in terms of art delivery. Each device will deliver single artwork in digital form. Scattering also allows to move some forms art to places with more ambience.

Example of usage:

- painter or graphic that creates landscape or urban architecutural drawings/paintings can deliver his/her artworks exacly in places where they ware created.
- sound artist or musician can move his/her creations to places with better atmosphere or vibe, that can improve reception.
- any artist can place devices in public spaces or bars, as form of expresion or self-promotion.

### 3. Extended content

Extended content is similar to substantive comment, but instead of delivering comment or other text it will deliver other art in digital form. It would fit in galleries, or at art exhibitions, where limited space (or budget) do not allows to put extra artworks.

- gallery with limited space can only display few painting out of series. Device can be used to present other painting if digital form.
- emerging artist, instead of only his/her illustrations would like to show also his/her digital movies. Setting up for example 4 TV or projectors require equipment that he has no access to, and is above his budget in case of renting or buying. Setting up devices allows him to present his other budgetwise.

## Instructions

These isntructions presents way of editing or creating HTML files that will work directly with device, without a need to change C++ code on ESP, and are based on examples provided.

### File structure

All files must be placed in data folder of project. They cannot be placed in any other folder and need to have specific names:

| File name | Description | Mandatory |
| --- | --- | --- |
| index.html | Main html file, webpage | Yes |
| style.css | CSS file with styles | No |
| background.jpg | Background image for better visual reception | No |
| image1.jpg | First of four available image files supported by ESP code | No |
| image2.jpg | Second of four available image files supported by ESP code | No |
| image3.jpg | Third of four available image files supported by ESP code | No |
| image4.jpg | Fourth of four available image files supported by ESP code | No |
| movie.mp4 | Movie file available to be included on webpage | No |
| sound.mp3 | Sound file available to be included on webpage | No |

Be aware, that image files must be saved as jpg, not jpeg.

There is no limit on size of files, but be aware that this is not a high speed connection. 100 mb video file will load in very long time, but will not play continously, since transfer speed is to low. Stick with small files. After uploading files test with your phone if it works smoothly.

### Text

Create any, simple HTML file. To format it, you can use for example https://html-online.com/editor/. Save it as index.html and place it directly on SD card.

or

Open index.html file in examples/text folder with notepad. Edit out *EDIT THIS TITLE*, *EDIT THIS HEADER* and *Lorem ipsum* to your desired text. Save it as index.html. You can add background file as background.jpg. If you do not add background file, background will be black and text will be white.

Place both index.html and background.jpg (optionally - you can skip this file) directly on SD card.

### Image

Use index.html file in examples/image. Copy it to SD card and add your desired image file, saved in jpg format and name it image1.jpg. Image will be displayed to fill the screen area. Remaining space will black.

You can use Windows Paint or any other graphic editor to save file as jpg.

### Image gallery

Use index.html file in examples/image_gallery. Copy it to SD card and add your desired image files (maximum of four), saved in jpg format and named as image1.jpg, image2.jpg etc. Images will be displayed as 2x2 grid miniatures with black background. Clicking miniatures will display full sized version.

You can use Windows Paint or any other graphic editor to save file as jpg.

### Movie

Use index.html file in examples/movie. Copy it to SD card and add your desired movie file in mp4 format and name it movie.mp4. File will be loaded as playable movie.

If your movie is not in mp4 file format, you can use any online video converter, for example https://www.freeconvert.com/. In video converters click on to mp4 and upload your video.

### Sound

Use index.html file in examples/sound. Copy it to SD card and add your desired sound file in mp3 format and name it sound.mp3.
You can also add an image (saved as image1.jpg) as cover photo.
File will be loaded as playable sound.

If your sound is not in mp3 format, you need to to convert it. Again you can use https://www.freeconvert.com/.

### Advanced

This example breaks hardware.

You can create any html webpage to archive desired look.

But there are some limitation. Each webpage must be:
- single leveled (no hyperlinks to other pages)
- maximum of 5 images can be used (one of them is background image)
- one CSS file can be used
- one video can be embeded
- one sound file can be embeded
- single page cannot have more external files than 4 (total of 5 files). No matter size.

Will change:
Example of advanced usage includes webpage with:
- 6 sections, each with header
- background image
- 4 of these sections contain text and one photo
- each photo can be clicked and enlarged
- one section contains video file
- one section contains sound file
- CSS file with styles for header and text

This setup covers basic scenarios and can be implemented without changes in project code.

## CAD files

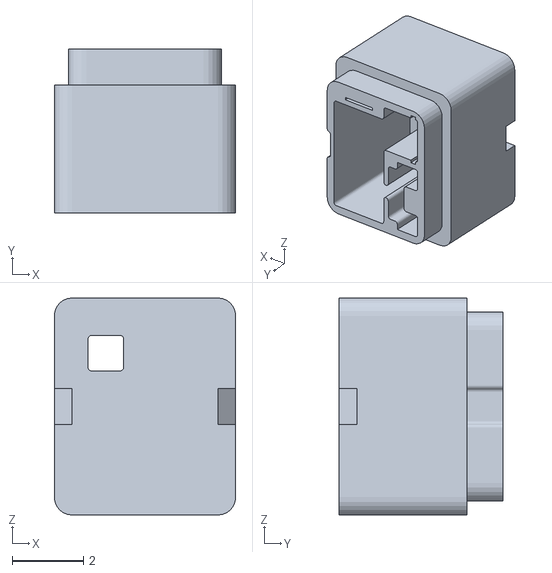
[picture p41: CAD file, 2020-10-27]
Case/2_batteries_lower_case.stl
5.10 x 4.60 x 6.10

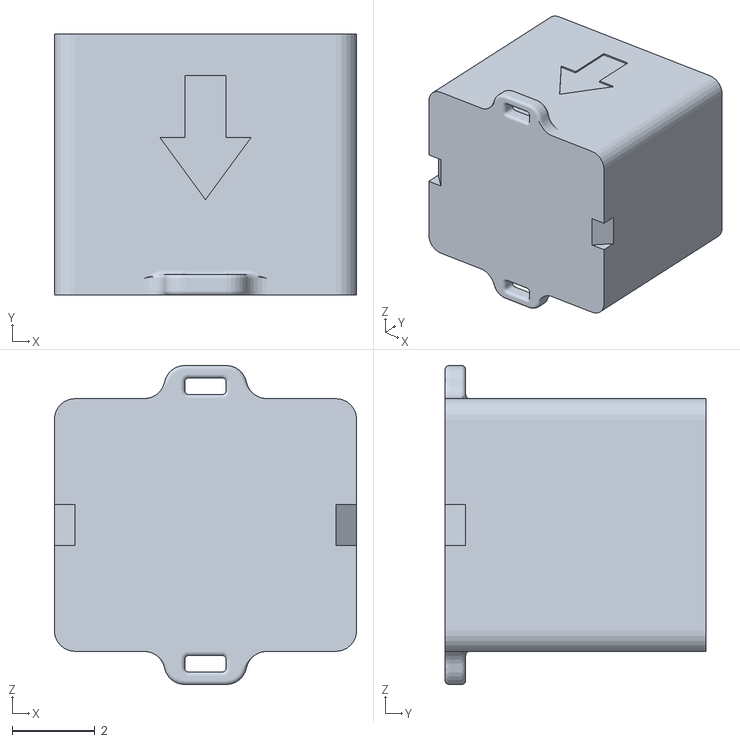
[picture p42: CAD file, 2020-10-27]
Case/4_batteries_upper_case.stl
7.30 x 6.30 x 7.70

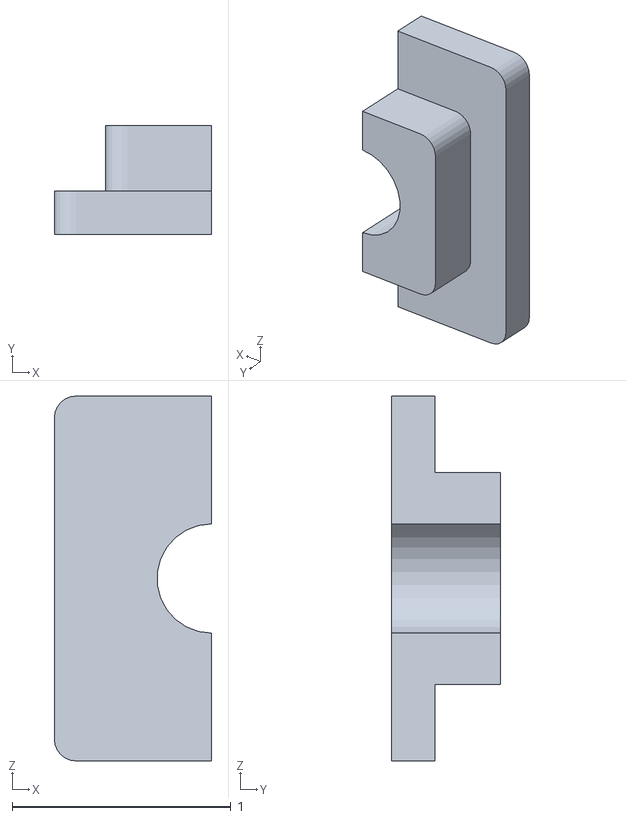
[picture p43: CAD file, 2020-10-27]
Case/stoper.stl
0.72 x 0.5 x 1.67

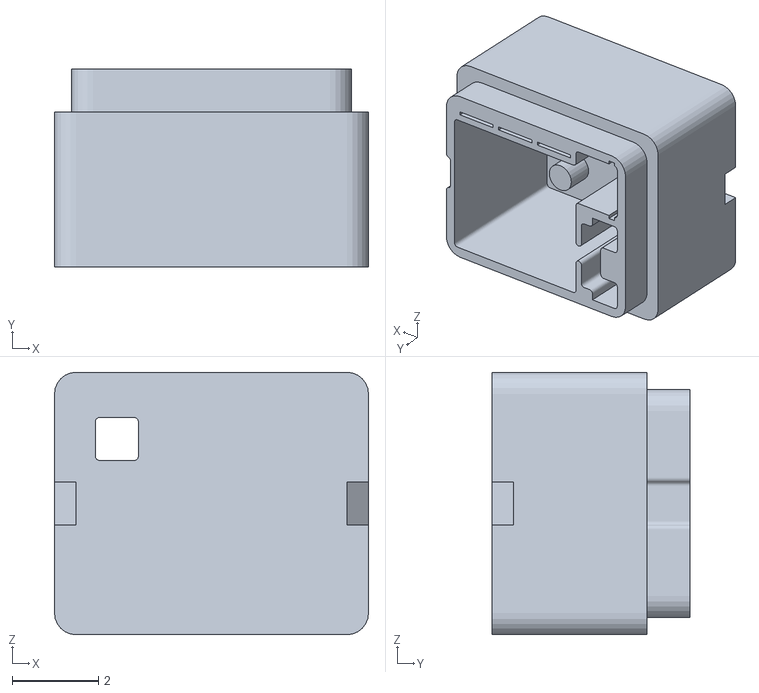
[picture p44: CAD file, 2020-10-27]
Case/4_batteries_lower_case.stl
7.30 x 4.60 x 6.10

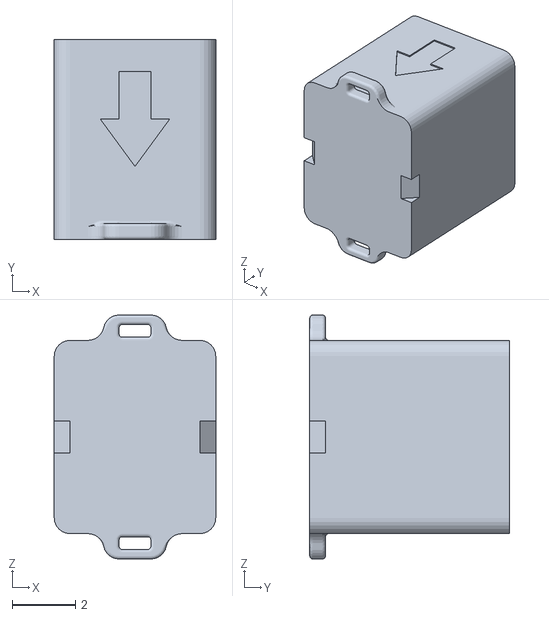
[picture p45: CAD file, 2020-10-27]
Case/2_batteries_upper_case.stl
5.10 x 6.30 x 7.70

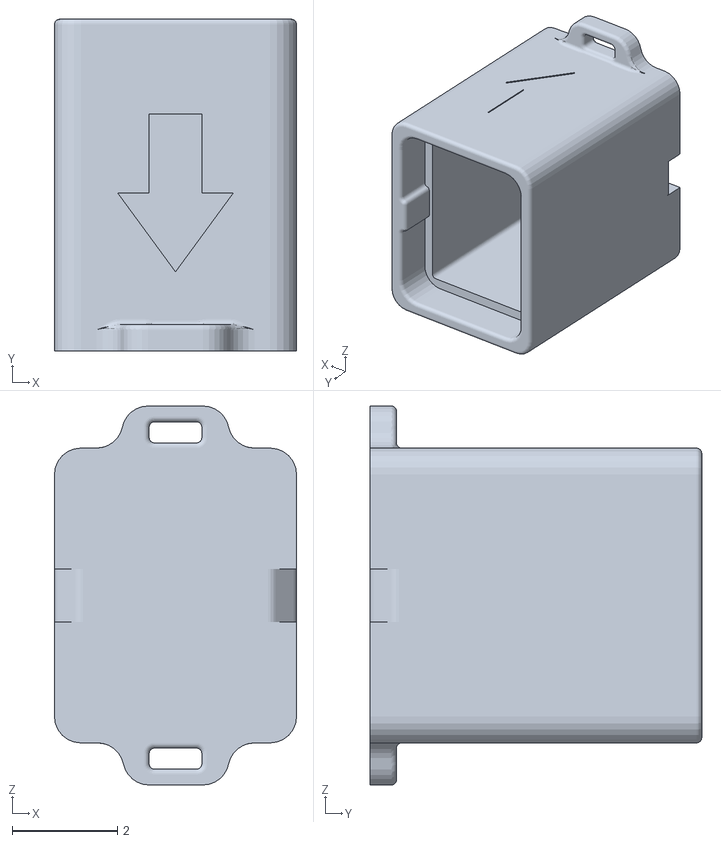
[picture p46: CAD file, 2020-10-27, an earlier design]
Legacy/Case/case 2 batteries/UPPER_CASE.stl
4.60 x 6.30 x 7.20

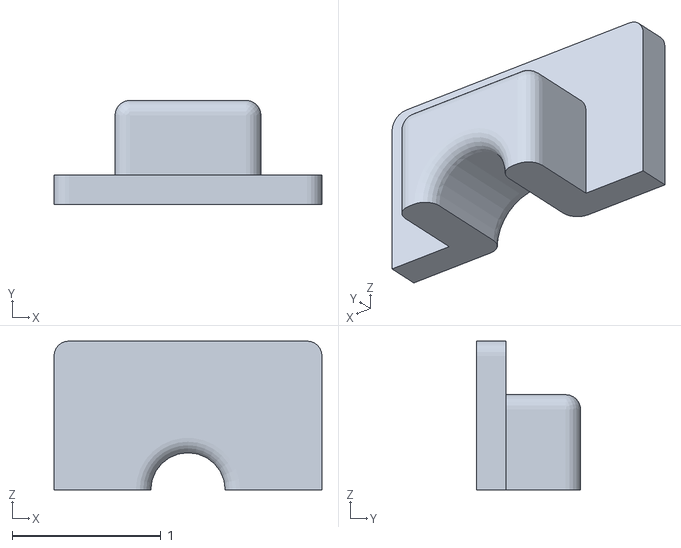
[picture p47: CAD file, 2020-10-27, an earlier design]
Legacy/Case/case 4 batteries/BOTTOM_PLUG.stl
1.80 x 0.7 x 1.00

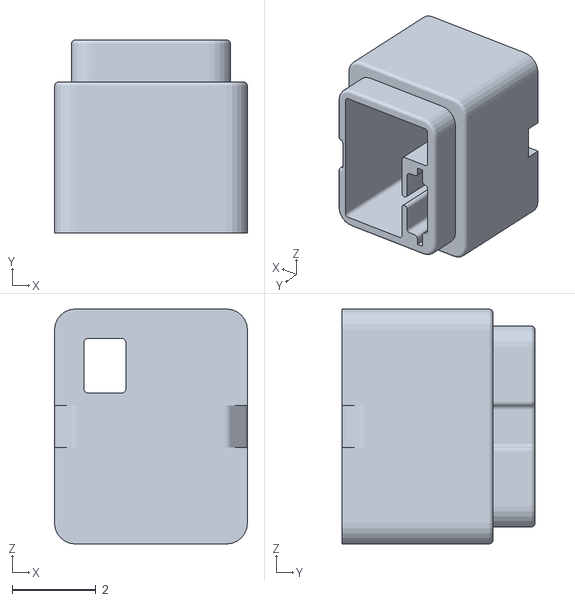
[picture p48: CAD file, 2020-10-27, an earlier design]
Legacy/Case/case 4 batteries/LOWER_CASE.stl
4.60 x 4.60 x 5.60
